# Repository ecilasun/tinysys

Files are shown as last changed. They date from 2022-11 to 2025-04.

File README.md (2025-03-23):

# tinysys

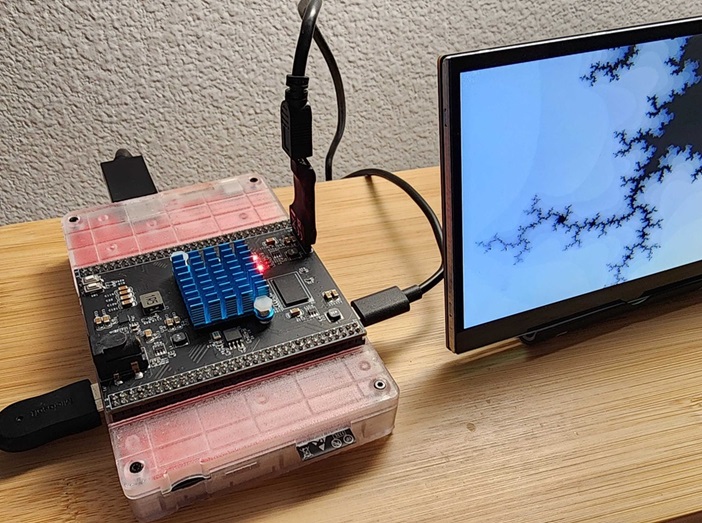
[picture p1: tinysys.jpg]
tinysys


# What is it?

Tinysys started out as a hobby project. It now has two RISC-V cores, and several other facilities listed below, and can happily run most software with minimal tweaks.

Of course, before you ask, it does run DOOM, and with sound and keyboard input! (Lately, it has been running Quake as well.)

# System specifications

- 2x RISC-V based CPUs (architecture: rv32im_zicsr_zifencei_zfinx)
- First core runs the OS kernel and user processes
- Second core is reserved for user processes
- 175MHz bus and CPU clock, semi-pipelined execution
- Vectored or direct interrupt support
- Supports instruction fence and data cache flush/invalidate operations
- Single precision FPU per CPU (no float control CRSs)
- Float and integer GPRs share the same register space (zfinx extension)
- 32 GRPs x 32 bits
- 4096 CSRs x 32 bits (some registers reserved for CPU and some are immutable)
- All CPUs have access to each-other's CSR register files via memory mapped addresses
- Integer multiply / divide units per CPU
- Software, hardware and timer interrupts per CSR per core
- 16Kbytes of direct mapped instruction cache (256 lines x 64 bytes)
- 32Kbytes of direct mapped data cache (512 lines x 64 bytes)
- 128 bit AXI4 bus with 32 bit address line
- Memory arbiter for on-board device system memory access (round-robin)
- Memory mapped external hardware (audio / video etc)
- HDMI 1.4b compatible video and audio output via external chip (12 bits per pixel, 16bps stereo 44/22/11KHz for audio, RGB or paletted modes)
- SDCard for file I/O
- 4 debug LEDs (also shared by OS as indicators)
- Custom preemptive multitasking OS, with file I/O and basic memory allocator via syscalls
- Optionally, a rom.bin image can be loaded from SDCard to replace the OS in ROM
- ESP32S3 on board for I/O handling (UART serial connected directly for CLI and other future connectivity, running at 460800 baud)
- Future revisions will use USB-OTG on the ESP32S3 module to allow for mass storage access to the device
- 16Kbytes mailbox memory for task scheduler + general purpose use (uncached)
- 16Kbytes of scratchpad memory for inter-processor communications or temporary data storage (uncached)
- Horizontal blanking interrupts to synchronize CPU with VPU for video effects or interrupt driven vsync page flip

# Overview of the processing units

## CPU
Based on 32 bit RISC-V ISA. Implements base integer instruction set, required cache operations (I$ and D$) and a large CSR file.
The core currently has an average instruction retirement rate of ~6 CPI (clocks per instruction) and runs at 175MHz, which
is also the speed of the AXI4 bus, where all peripherals and memory reside.

### Fetch/Decode/IRQ
This unit reads an instruction at PC, decodes it and outputs it (together with its PC) to instruction output FIFO (IFIFO). If it's an interrupt entry/exit or some other special instruction (for instance I$ flush) then it is handled entirely within the fetch unit. This unit is also responsible for inserting pre/post interrupt code from an internal ROM at interrupt or exception time. Conditional branches will place fetch unit into an idle state, where it will wait for the execute unit to resolve the target branch address. This means there's no branch prediction on the CPU just yet.

### Execute/Load/Store
This unit will read an instruction from the IFIFO if available, load registers with values, execute (ALU/BLU/CSR/SYS) and decide on new branch target if there's a branch involved. After deciding on the branch address, fetch unit is notified so it can resume instruction fetches. Where possible, load or store operations will attempt to overlap with fetch and execution.

## VPU
Video processing unit. Handles scan-out of various video sizes (320x240 and 640x480) and bit depths (8bpp index color or 16bpp RGB color). It contains a scanline cache which is populated via burst reads from system memory, from which either a scan-doubled or single line is output to the display, based on video mode height. The device allows for mid-frame change of resolution via hblank interrupts.

## APU
Audio processing unit. Handles RAW audio outputs, and also manages 44/22/11KHz stereo playback and double-buffer handling of RAW audio.

# Overview of the bus

## AXI4 bus
The AXI4 bus, running at 175MHz, connects all of the processing units to memory or devices. In the case of memory, access is cached per perhipheral as needed. Memory mapped device access is always uncached.

# Contributors

```
Martin Hedlund

  tbm_vsnprintf() and tbm_printf() functions

Wade Brainerd

  fcvtswu4sat instruction
```

# Custom instructions

## Convert from float to 4 bit integer, saturated (FCVTSWU5SAT)

This instuction has been contributed by Wade Brainerd. It's very useful in converting floating point values to device specific 4 bit color values.

The following python script helps encode a hex representation of this instruction, for convenience:

```
op = 0b1010011		# OP-FP (floating point operation)
rd = 0b01010		# destination register - a0 in this sample (a0 == x10)
rs1 = 0b01011		# source register - a1 in this sample (a1 == x11)
funct7 = 0b1100001	# funct5 F7_FCVTSWU5SAT - this is our new sub-instruction
inst = op | (rd << 7) | (rs1 << 15) | (funct7 << 25)

print(f"{inst:x}")
```

You can then use it in code as follows:

```
inline uint32_t ftoui4sat(float value)
{
  uint32_t retval;
  asm (
    "mv a1, %1;"
    ".insn 0xc2058553;" // fcvtswu4sat a0, a1 // note A0==cpu.x10, A1==cpu.x11
    "mv %0, a0; "
    : "=r" (retval)
    : "r" (value)
    : "a0", "a1"
  );
  return retval;
}
```

P.S. For the future we might be able to do this natively on a RISC-V or propose an extension for arbitrary saturation for custom formats.

# Software

Please see [README.md](./software/README.md) for details on software samples, ROM and prerequisites for building ELF files.

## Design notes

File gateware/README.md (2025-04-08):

# Latest Gateware Build is: 00203
# Latest OS ROM version is: 00152
# Latest ESP32 ROM is: r1.1H
# Latest Board version is: 2H

# Gateware binary
The gateware binary contains latest version of the device.
There is no need for a ROM file.<br>
If you have an older one, you can simply delete it, or use a `rom.bin` file with this version or higher.

# Current device architecture
This is the current architecture to use with gcc13 and higher: `rv32im_zicsr_zifencei_zfinx`

# ROM history
r1.01: Initial release version<br>
r1.03: Improvements for dual core boot stability, fixed audio hardware playback rate issue<br>
r1.06: Minor improvements to inner ROM loop and some other bug fixes<br>
r1.07: DMA hardware change in preparation for misaligned DMA support<br>
r1.08: Stability fixes<br>
r1.09: Added misaligned DMA support and removed ESP32/FPGA GPIO bridge device (to be re-done later), also added hblank interrupt mechanism and remote reboot ability (~ character over UART)<br>
r1.0A: Added 64Kbytes of scratchpad RAM, shared across all cores, WNS relaxed to leave room for any future bug fixes<br>
r1.0B: Minor device cleanup, reduced scratchpad to 16Kbytes, bumped mailbox to 16Kbytes<br>
r1.0C: Added a third CPU, CLI improvement to ROM and other minor fixes<br>
r1.1D: Improvements to reboot / task system and more ROM code cleanup, also updated file upload routines<br>
r1.1E: Updated UART to run at 460800<br>
r1.1F: Completely switched to ESP32S3 and new board(2G), added reset lines to UART, some helper tool and CLI improvements<br>
r1.1H: Removed DMA hardware due to complications, added experimental HDMI output for video/audio<br>
r1.3H: Some timing fixes and ROM code cleanup<br>
r1.4H: Slightly better timing, some hblank SDK and hardware work done (still not stable enough due to IRQ handling mechanism)<br>
r1.5H: Reduced I$ turnaround by one clock on cache hit<br>
r1.8F: Removed hblank device, updated ROM with fixes to task logic<br>
r1.9A: ROM updates with OS side input handling, software updates to match<br>
r1.9B: Minor changes to ROM and SDK routines, updates samples<br>
r2.0A: Added vectored interrupt support and bumped clock to 175MHz<br>
00201: Changed gateware versioning scheme, changed reset logic to full FPGA reset (clock and all clocked devices)<br>
00202: Task stack sizes bumped to 16K from 1K, watermark register now does not survive hard reset (only soft reset)<br>
00203: Bumped scratchpad to 64K, reset is more robust, updated ROM image with some memory fixes<br>
00151: OS updates for task errors<br>
00203: OS changes to same device version<br>
00152: OS changes (mainly for ELF loaded memory stomp)<br>
00203: Fixed float->uint conversion bug, keeping hardware version same<br>

# Device gateware

This folder contains the gateware that will reprogram the FPGA board on tinysys to a functioning RISC-V CPU with several other peripherals.

The intended device is the QMTECH A7200T core board, which is a blank FPGA board with nothing but an XCA7200T AMD/Xilinx part and a 256Mbytes DDR3 memory. The firmare also needs at least a revision 2E tinysys board to be attached to it to provide USB serial / HID / audio and video connections as well as the sdcard port.

Programmin the gateware onto the device requires a JTAG adapter (such as the HS2 REVA from Digilent or a Xilinx compatible 6-pin adapter), a PC, and Vivado 2024.1 installed.

NOTE: Make sure to never attempt this unless absolutely necessary and a hardware bug needs addressing / fixing or a new feature is added to the device!

# Programming

First we need to attach the JTAG adapter to the PC, and make sure the Vivado drivers are installed for it.

For this step, attach a USB cable to the HS2(revA or later), attach one end to your PC, then attach the adapter end to the 6 pin connector on the already powered-up FPGA board, as seen below:

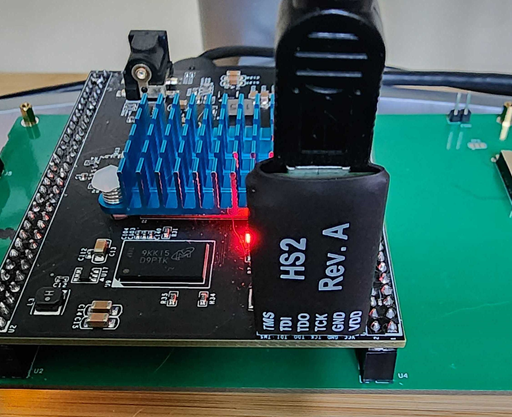
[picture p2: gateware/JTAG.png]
JTAG Connector


When properly connected, the text on the HS2 should be facing away from the board (easiest way to make sure it's correct is to find the GND marker on the 6 pin connector on the FPGA board, and line up the GND marker on the HS2 to that)

Start Vivado 2024.1 (or newer version) and on the first page, select Open Hardware Manager.
You should then see a note that says 'No hardware target is open.' Click the `Open Target` button next to it and select the `Auto Connect` option.

This should bring up a view which shows a 'xc7a200t' device listed. Right click on it and select `Add Configuration Memory Device`
In the search box, type `is25lp128f-spi-x1_x2_x4` and accept the changes.

Now this memory device should be listed unde the xc7a200t device, most likely below a XADC device.

Right click on the is25 and select `Program Memory Configuration Device`, then browse to and select the `tophat.bin` file in the gateware folder for the Configuration File.

Click OK and wait until the device is programmed (which will take a minute or so)

Once the progamming is complete, the device will not function until it's reset. Press the program/reset button (the small white button closer to the power connector barrel) and the device will reboot itself with the new gateware.

NOTE: the ROM image used by an updated gateware may differ from the one on the sdcard, make sure to either delete the one on sdcard or update it to a version newer or same as the gateware one, to ensure correct operation.

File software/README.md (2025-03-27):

This folder contains the riscvtool helper utility, the ROM image, sample code and the SDK for tinysys.
> Please note that precompiled binaries for riscvtool have been provided for Windows and Linux, however if the supplied binaries do not run for you or if you wish to build a MacOS version, please rebuild them from source as explained below.

# Prerequisites

If you wish to actually run things on a real piece of hardware:
- If you did not acquire / build one, please find the KiCad files for the board and go through the paces to build one
- Next step is to acquire (or use an existing) QMTECH A7200T core board (I'll build my own single board computer later, promise!)

If you wish to work on software:
- To be able to compile your own executables, or ROM images, you'll need a prebuilt gcc risc-v toolchain from the following link.
<br>(NOTE: The default compiler setup for samples and ROM images uses gcc, so please make sure to get that package)
<br>https://embecosm.com/downloads/tool-chain-downloads/#risc-v-embedded-stable-release-compilers
- In case you need it, you can find 'make' binaries here:
<br>https://gnuwin32.sourceforge.net/packages/make.htm
<br>(Make sure to also install libintl3 from same source and make sure it's on the path as well as the make.exe from the bin package)
- If you wish to build your own ROM images, you'll also need a working python3 install to make sure the waf build system functions as intended.
- To be able to compile riscvtool, you'll also need a working cpp compiler targeting the platform you're going to build on (windows/linux/macos etc)
- I advise using Visual Studio Code, but it's optional (all step below try to show both VSC and command line usage)
- To compile the ROM image and program the ESP32-C6 device (our communication module) for the first time, you'll need to install ESP-IDF addon for your Visual Studio Code
<br>See https://github.com/espressif/vscode-esp-idf-extension/releases/ for latest release

Or if you wish to simply browse / copy code or hardware details, feel free to do so, and don't forget to credit me and other people for their respective work!

# Build riscvtool (optional, required to build a new OS ROM)

If you wish to build new ROM images to experiment with, you'll need riscvtool which will generate the ROM binary format required by tinysys. You'll need a working python3 install for the following steps to work.

To build in Visual Studio Code:
- Open the 'software' directory in Visual Studio Code so that the root path is now /tinysys/software
- Use the ctrl+shift+b shortcut in Visual Studio Code and select 'configure'
- You can now ctrl+shift+b again select 'build', which will compile and generate the riscvtool for your platform

Alternatively, you can use the following command line sequences:
```
# To configure (required only once):
python waf --out='build/release' configure

# To build after code changes:
python waf build -v

# To 'clean' the output binaries
python waf clean
```
PS: The build process for riscvtool is the same on Linux and Windows.

# Building ELF executables

Please see [README.md](./samples/README.md) file in the samples directory

# Building ROM images

NOTE: Ordinarily you don't need to (and should not) build ROM images, there is one built into the gateware provided in the /gateware directory.

This is similar to building the samples, simply switch to 'ROMs/boot' directory and type:

```
make
```

This will give you one .mem file, and .elf file and a .bin file. The .elf file is not useful as a ROM image in this case, so you can ignore it.

The .bin image goes onto the sdcard, inside the '/boot' directory at the root of your FAT32 formatted sdcard. This image will be loaded by the resident ROM image and the device will chain to the code you've placed in this file, which is essentially how an OS update works for tinysys.

The .mem image is the actual physical ROM version of the same binary. If you don't plan to use an sdcard, the contents of the .mem file should be pasted over the 'Memory File/romimage.mem' file you can find in the project view. After replacing it, don't forget to 'Reset Runs' / 'Generate Bitstream' to generate your new gateware. (I recommend doing development using the .bin image and only replace the .mem once you're sure it's working to avoid lengthy development times, gateware usually takes about 20 minutes each run on a modetately fast desktop PC)

# Programming the ESP32 communications firmware

Tinysys uses an ESP32-C6 to communucate with the outside world. For this to function properly, the ROM image for the ESP chip has to be built. You need first plug in the previously-unprogrammed tinysys device, then open 'software/ESP32S3/defaultrom' in Visual Studio Code, and Hit the ESP-IDF 'Build, Flash and Monitor' button (looks like a little flame) to build and deploy it to the device.

# Default SDCard layout

Tinysys OS expects to find certain files in certain paths to function as expected. For instance, the 'rom.bin' file is expected to be in the '/boot' directory at the root of SDCard. Tinysys OS supports commands that can be executed from any directory (sort of a fixed $PATH if you will), and this is always expected to be 'sys/bin' Anything in that directory can be run from anywhere. Therefore it's a good place to put OS utilities or any used code that you might want to run from any path.

Therefore the default SDCard layout is:

```
sd:/sys/bin/... <- utility binaries, accessible from anywhere
sd:/sys/bin/rom.bin <- ROM overlay is always located here
```

# Creating your own project

To make your own project, the recommended way is to copy the 'hellodebugger' sample directory to a new one and make your changes as needed. In that directory you will find a Makefile, and upload shell script/batch file to help get you started.

Please refer to the [README.md](./samples/hellodebugger/README.md) file in `hellodebugger` folder for more assistance.

# Uploading your files to tinysys

There is an executable on the default disk image of tinysys, called 'recv.elf', under the sys\bin directory. The riscvtool binary can start this application remotely and start sending a binary file to it.

The syntax for sending a file is:
```
On windows:
riscvtool -sendfile myfile.elf
On Linux and MacOS:
./riscvtool -sendfile myfile.elf
```

The recv.elf executable will show an upload progress, and make sure the file arrives safely before writing it to the sdcard, as well as report any errors that might occur during the transfer.

# Other notes

NOTE: All software has been tested with and geared to use a gcc-riscv 32bit environment under Windows and Linux, but as always one might fall behind the other at times.

# Acknowledgements

I'd like to thank Wade Brainerd for help in getting this device tested thoroughly in a live environment, and for the awesome saturated float to integer conversion instruction.

Also thanks goes to Ben Stragnell for great advice and pointers in how audio hardware should work.

Further thanks goes to everyone who's build something on this machine at least once to put it through its paces.

Happy hacking!

Copyright 2025 Engin Cilasun

Please see respective license.txt files for individual license terms

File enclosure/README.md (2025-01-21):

# Enclosure

This directory contains SOLIDWORKS files for the enclosure, generated around board revision 2H

Enclosure:
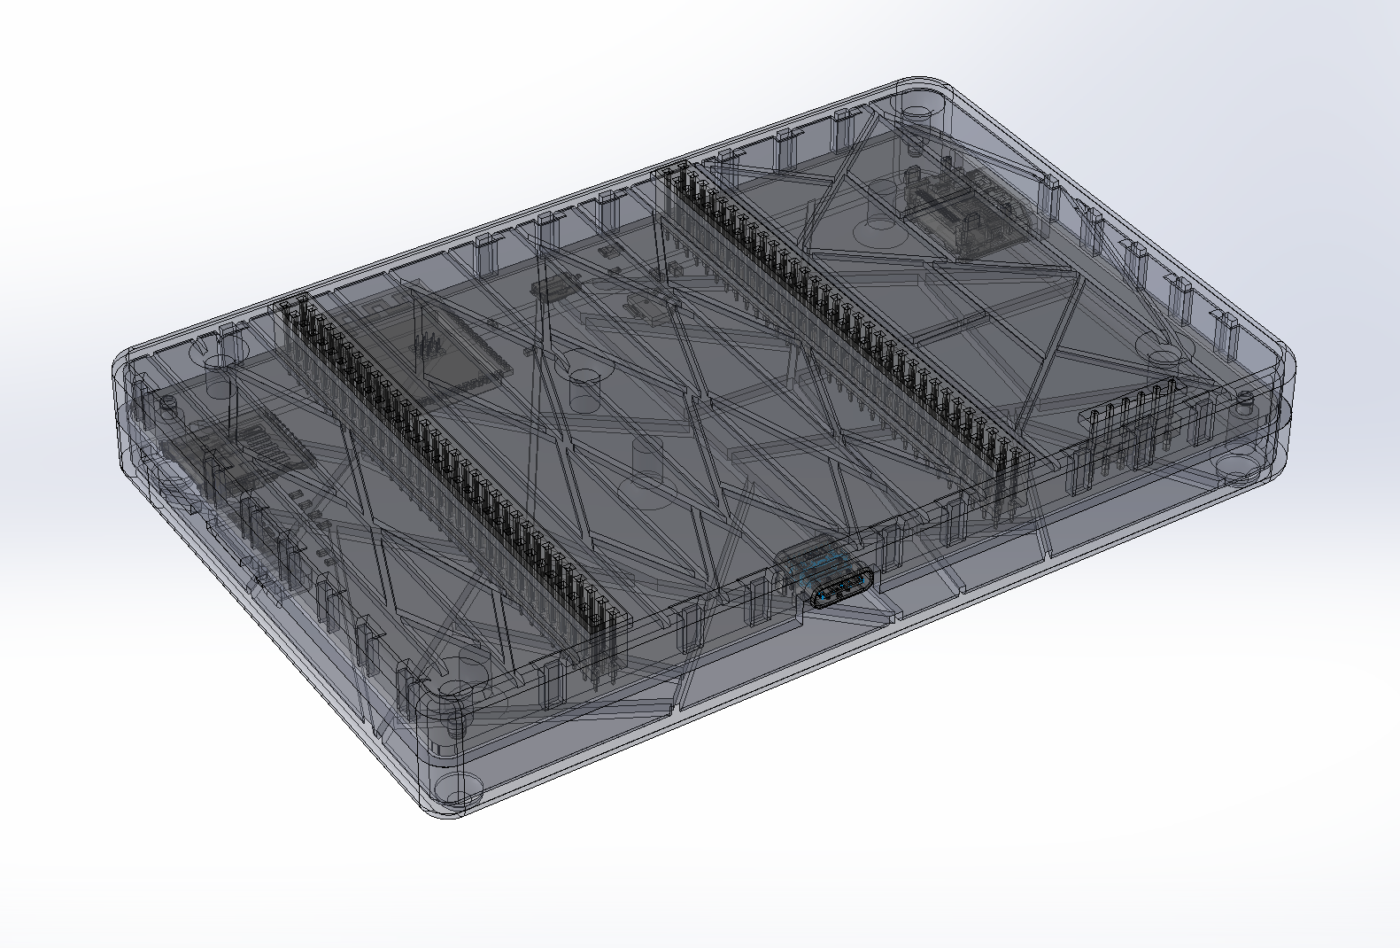
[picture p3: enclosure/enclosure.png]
Enclosure


Bottom:
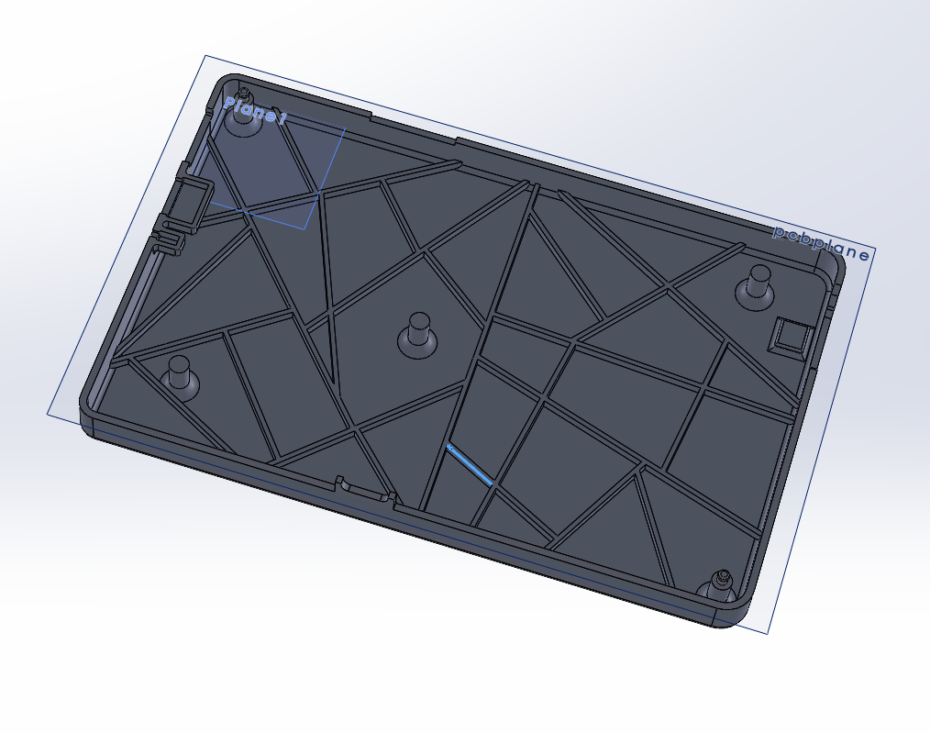
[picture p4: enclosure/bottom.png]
Enclosure Bottom


Top:
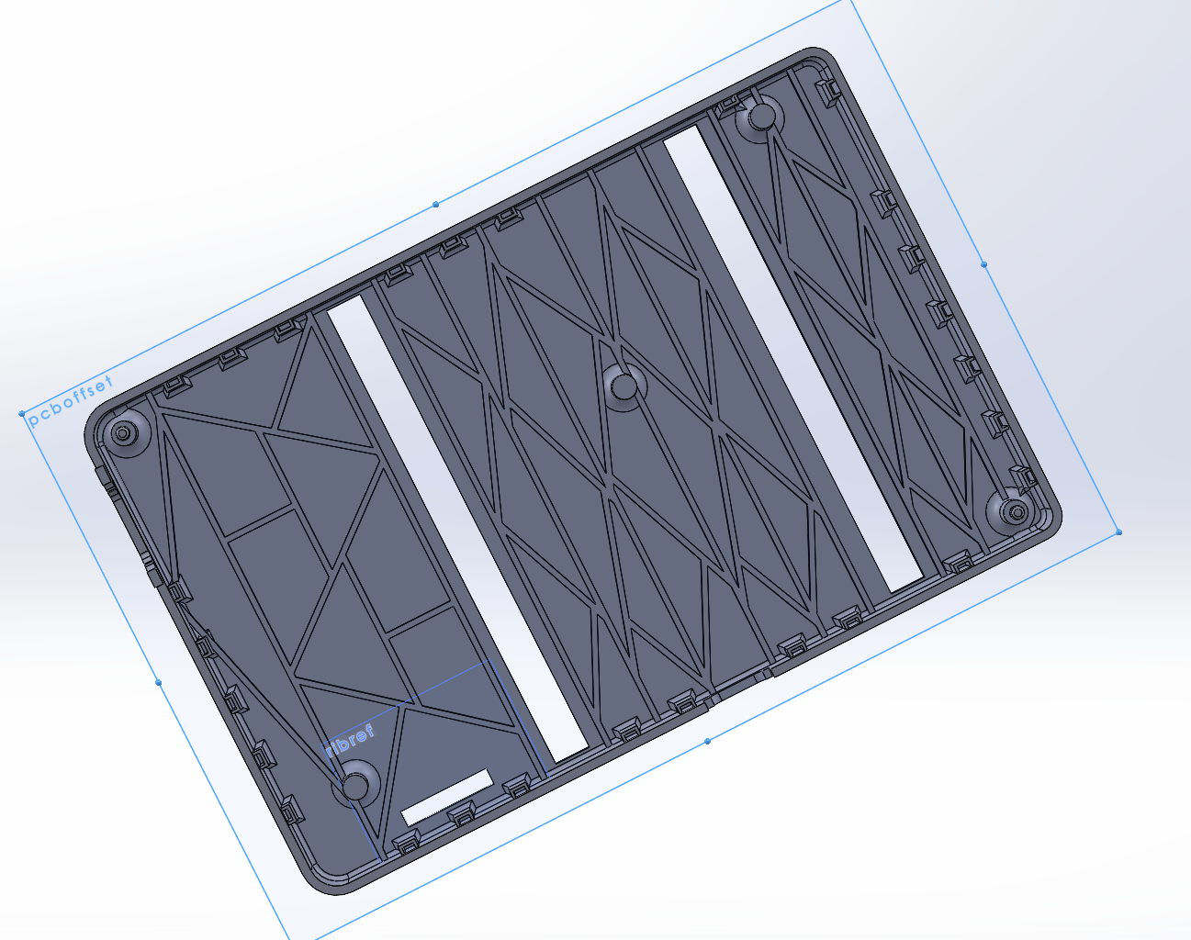
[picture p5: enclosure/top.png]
Enclosure Top


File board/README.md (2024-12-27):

# expansionboardA

This repository contains KiCAD 7 project files for an expansion module built for QMTECH A7 200T core board.
Required libraries (models and symbols) are included with the project.

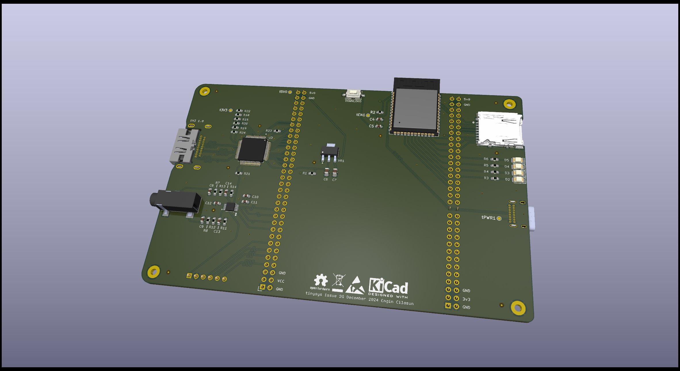
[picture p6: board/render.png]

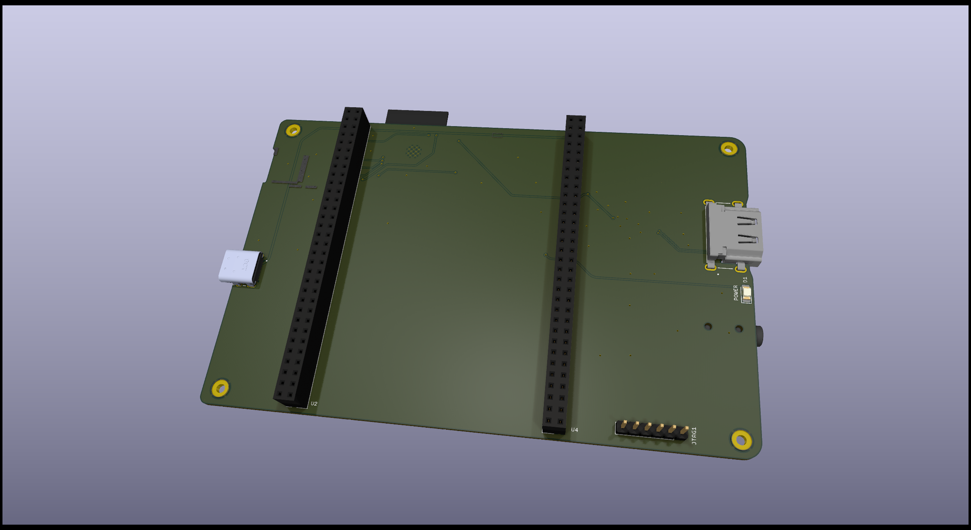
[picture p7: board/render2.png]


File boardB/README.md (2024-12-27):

# expansionboardB

This repository contains KiCAD 7 project files for an expansion module built for QMTECH A7 200T core board.
Required libraries (models and symbols) are included with the project.

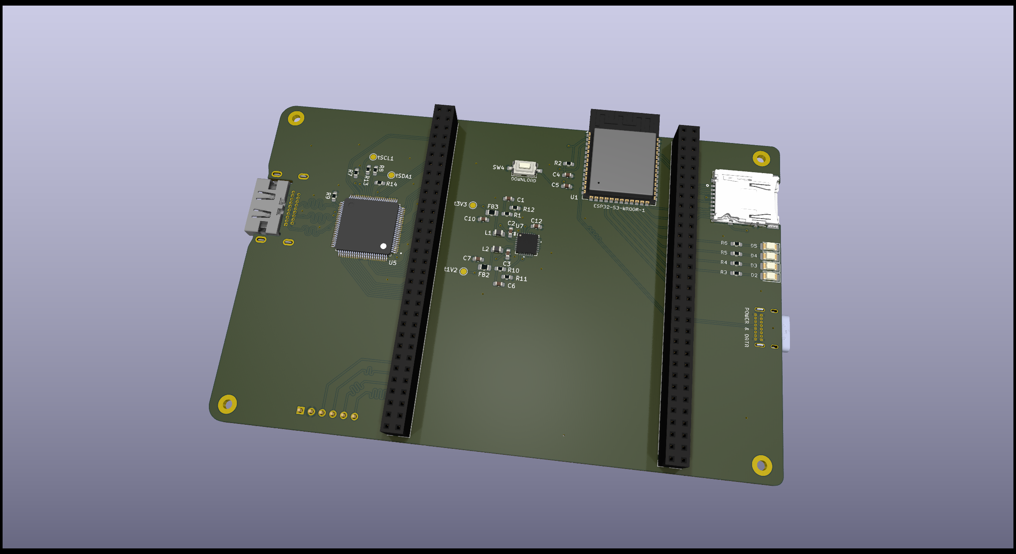
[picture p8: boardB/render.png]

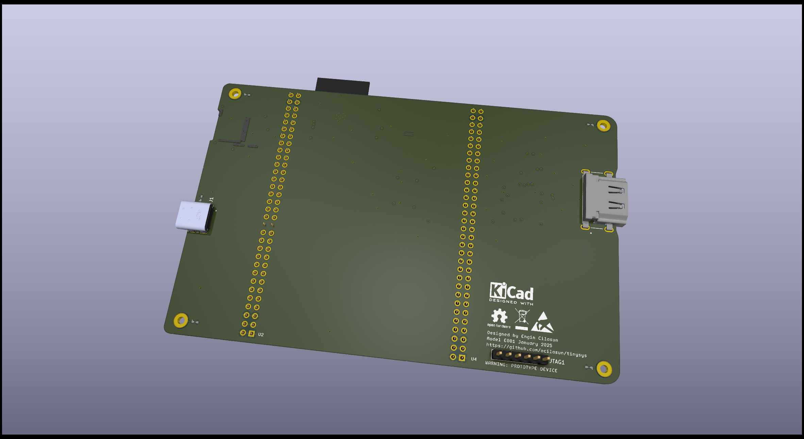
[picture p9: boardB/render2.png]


This board revision aims to unify audio and video into one device, and add a proper voltage regulation circuit. This revision is a 4 layer board instead of the previous 2 layer board.

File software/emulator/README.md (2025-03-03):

# What is this?

This is an emulator for the tinysys project

# Prerequisites
To build, please make sure you have at least version 2.3 of the following libraries available:
- libsdl2-dev
- libsdl2-ttf-dev

# Usage
To build the project, make sure you have C++ VC compiler tools installed, use the following sequence:
```
python3 waf configure -obuild/release
python3 waf build
```

Alternatively, you can use Visual Studio to build the emulator, using the emulator.sln solution file in the emulator/ folder

This will copy the emulator executable to the bin directory of project root folder, which you can then run using:
```
emulator.bat
or
./emulator.sh
```
depending on your OS.

The emulator will then scan the *sdcard* directory for executable files and generate a fake SDCard layout in memory which the emulator can access as if it's a real device.

To test your app, make sure the emulator is not running, drop your binary into the sdcard folder, and then start the emulator.

Following that, you can then run it by typing the name of your executable, excluding the .elf extension.

P.S. The emulator has been tested on latest macOS and Windows 11, Linux builds might require some manual work.

# Details

Here's a list of features implemented so far

- Dual CPU cores work with FPU (custom float->sat instruction included)
- Interrupts work
- UART is tied to console (I/O)
- Video output works
- There's a CPU stats overlay: update wscript to include the CPU_STATS define and rebuild if you wish to use it
- CSRs and their special purpose registers work
- MAIL device works
- LED device work with graphical representation present
- APU works and plays sound via SDL (including all playback frequencies supported by the real hardware)
- SPI sdcard emulator fully works
- GDB stub is working to a certain point, needs better breakpoint handling and single step support

And here's the list of what's missing

- ESP32-S3 module emulation is missing and won't be supported (don't want to deal with Xtensa emulation at this point)

Please note that this is not a clock precise emulation and instructions will almost always retire in 1 CPU clock. Also all devices clock at the same speed so there's going to be some mismatch there as well. Since the aim of this emulator is to provide a testbed for ROM or user software in the absence of real hardware, it should be close enough to get development rolling.

Wish list

- TODO

### Back to [SDK Documentation](../SDK/README.md)

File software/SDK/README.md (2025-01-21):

# SDK Documentation

## Base System
Base system routines provide useful facilities such as reading the clock, or setting up critical sections.

Please see [BASE](base.md) for documentation about base system utilities.

## Audio Processing Unit
The audio processing unit is responsible for generating stereo signals at various output frequencies.

Please see [APU](apu.md) for documentation about audio.

## Multitasking
The task library helps start and stop tasks that can run on any hardware thread in the system.

Please see [TASK](task.md) for documentation about multitasking and the CPU cores.

## Video Processing Unit
The video processing unit controls video scan out from selected system memory location as well as controlling color depth and video dimensions.

Please see [VPU](vpu.md) for documentation about video output control.

## Debug LEDs
The debug LEDs provide an easy means to debug code when there are no alternatives, or to show status.

Please see [LED](led.md) for documentation about debug LEDs.

## Emulator
The emulator tries to provide as close an experience to the real hardware as possible, including a virtual SDCard interface to make development easy.

Please see [EMULATOR](emulator.md) for documentation about debug LEDs.

## Low level hardware overview
The hardware of tinysys consists of an FPGA board that carries some custom devices and two RISC-V cores. The FPGA board lives on a custom board that contains some external peripheral chips that interface the board to the outside world, such as video, audio and USB connectivity.

Please see [HARDWARE](hardware.md) for brief information about the internal devices.

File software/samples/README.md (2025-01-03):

This folder contains the samples for tinysys

# Building samples

To build all of the samples, use the following command in this directory:

```
make
```

This will produce .elf binaries in each of the sample folders, which you can then copy onto an sdcard and run on the device.

If you wish to build just one, change to the desired folder and use the same make command.

# Running samples on the emulator

This initially requires you to build the emulator binaries.

First, check out the [README.md](..\emulator\README.md) for build instructions.

Once the emulator is built, next step is to drop your binary into the [sdcard](..\emulator\sdcard\README.md) folder and then start the [emulator.bat](..\emulator\emulator.bat) file.

The emulator will do its best to match the hardware, except the ESP32 device which is not currently emulated.

# Running samples on the actual device

Once the dev environment is set up and riscvtool has been compiled, first switch to the desired directory on the device using:

```
cd somedirectory
```

then use the following command to send files across to the actual device:

```
On windows:
riscvtool -sendfile myprogram.elf

On Linux and MacOS:
./riscvtool -sendfile myprogram.elf

Alternatively, you might want to provide a COM port name:
riscvtool -sendfile \\.\COM6 myprogram.elf
```

followed by the name of your binary + Enter:

```
myprogram
```

to execute the binary.

The file transfer code will split the file into chunks, lz4 pack them, and send them across serial connection to be reconstructed into a file on the device.

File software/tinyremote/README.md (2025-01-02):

# TinyRemote

Tinyremote can be used to connect to a tinysys board on a remote machine and control it while being able to see the video output.

Currently it only supports Linux and Windows, but future support for MacOS is also in the works.

Build prerequisites on Linux:

```
sudo apt-get install libx11-dev libv4l-dev libv4l-dev libsdl2-dev libsdl2-ttf-dev
```

Windows includes the required SDL headers and binaries in the 3rdparty folder.

For MacOS, SDL2 and SLD2_ttf have to be installed via homebrew and reside in the following paths at the time of writing:

```
/opt/homebrew/Cellar/sdl2/2.30.5/include/SDL2
/opt/homebrew/Cellar/sdl2/2.30.5/lib/

/opt/homebrew/Cellar/sdl2_ttf/2.22.0/include/SDL2
/opt/homebrew/Cellar/sdl2_ttf/2.22.0/lib/
```

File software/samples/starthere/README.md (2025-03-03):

# Welcome to your project!

First step is to create a copy of this folder under the samples directory, and rename it to match your project title.

After this, you'll want to rename the output file names from `starthere` to your project name in the Makefile.

Once that is out of the way, we can begin!

# What is this tinysys?

Tinysys is a simple computer with two 32 bit RISC-V cores. It has no branch prediction, no pipelining and will run at approximately 27MIPS, and has a coremark score of 0.54 to 0.6 depending on the configuration

However slow it might seem, it makes up for what it lacks with a few hardware devices implemented in the FPGA fabric. To see the speed at which memory can be moved around, run the `memtest` sample for CPU side memory clear speed.

There's a mini OS (~52Kbytes) provided in ROM which contains the necessary routines to help with file access, memory allocation and other facilities.

The SDK directory contains quite a few modules and combined with the samples you should have a good idea of what the device can achieve.

# Compiling and running your project

Tinysys is a very simple machine so it requires little more than a few files to do something useful. Observe the layout of the provided Makefile and make necessary changes as you see fit. Only thing to watch out for are the machine architecture and cache size/alignment flags. Rest is up to you!

To run the resulting .elf file, you have two choices.

You can use the riscvtool to send the compiled binary to the machine using base64 encoded format. First, got the directory where your binary is, and use the following command:

```
On windows:
riscvtool -sendfile myfile.elf
On Linux and MacOS:
./riscvtool -sendfile myfile.elf
```

This will start a progress bar and copy the file to the target device, however since base64 encoding expands a file, it will not complete this transfer quickly. The file is written to the SDCard at the current directory.

Alternatively, you'll need to copy your binary onto a FAT32 formatted SDCard, insert the card into the machine.

After either method, type the name of your binary (without the .elf extension) from a connected terminal or keyboard, and the binary will start executing.

If you wish to stop execution, use CTRL+C to break out of the application.

If your system appears to be unresponsive, use the tilde key (~) to break the execution from a connected terminal (this will not work with a keyboard, in that case assuming you're close to the device, please use the reset button on the board instead)

# Debugging this sample

'starthere' sample is deliberately unoptimized to act as our debugging sample. To start debugging, first start the executable from the samples directory on the emulator. Then, from the tinysys\software directory, run the following to load the debug symbols and start a GDB session:

```
riscv32-unknown-elf-gdb.exe -x gdbcmd samples/starthere/starthere.elf
```

This will start GDB but assume the remote executable has stopped when it's connected. At this point you can add a new breakpoint using the 'b' command and then use 'c' to continue exectuion. This will update the breakpoints on the device and stop execution on the closest line possible (depending on optimizations and line number information available to GDB)

Alternatively, start the sample on the device and open the software folder in VSCode, then hit 'Run' which by default loads the 'starthere' sample debug data. You can now debug on the device as usual. Please modify the launch.json file and change the "program" entry to your own executable as needed.

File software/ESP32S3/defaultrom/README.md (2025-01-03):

# Firmware for the on-board ESP32-S3-WROOM-1 module

This firmware allows the ESP32 to act as a communications processor for tinysys.

The default firmware behavior is to pass through serial data coming from USB to the UART pins connected to the FPGA and also provide the same function in the opposite direction.

In additon, sending the character '~' with no following character within a certain amount of time will pull a reset line to reboot the CPUs on tinysys, therefore the ESP32 can be used as a recovery device for code that gets stuck when developing remotely (when no button access is possible)

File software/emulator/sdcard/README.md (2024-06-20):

Drop the contents of this folder to the root of a FAT32 formatted sdcard, place it into the tinysys board's sdcard slot and reboot.
This will get tinysys to reboot from the .rom image on this folder and you'll have all the samples precompiled so you can test them quickly.
NOTE: The elf files in the sys/bin directory can be run from any folder, so you might want to place any new binaries that you wish to use as 'commands' into that folder.

In addition, this folder will be used by the emulator so you can test the samples without having to flash the board.

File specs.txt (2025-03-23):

CPU:
32 bit CPU running at 175MHz, approximately 5 clocks per instruction
Vectored or direct interrupt support
Based on RISC-V architecture
Implements the rv32im_zicsr_zifencei_zfinx feature set (32bit base instruction set, intereger div/mul, combined float+integer register file, 4096 control/status registers, I$/D$ fence and flush instructions, software/hardware/timer interrupts)
16Kbytes instruction cache
32Kbytes data cache
64Kbytes of ROM for the OS
No branch prediction
No pipelining
No memory management unit (i.e. no virtual memory)

Memory:
256MBytes of DDR3 SDRAM
Cached access from CPU and direct access from other devices on the bus, in 128bit bursts

Devices:
Memory mapped access to the following devices:
- Device temperature monitor, accessible from user software
- Video and 16 bit stereo audio over HDMI port (640x480 or 320x240 modes with 8bpp indexed or 16bpp truecolor for a total of 4 modes)
- SDCard slot
- USB-C port for serial connection to a host PC / power
- USB-A port for peripheral connectivity
- 4 user / debug LEDs (currently used by OS for status indication, user software can also access these)

OS:
Custom OS in ROM with preemptive multitasking, copied to RAM at boot
Can instead chain to user binary from SDCard (rom.bin at root)
Runs ELF files generated by riscv gcc13 directly (riscv64-unknown-elf-gcc with 32 bit output)
Implements memory allocation (s_brk) and file IO syscalls
Handles serial I/O via MAX3420E
Handles host features via MAX3421E and implements host device drivers (keyboard/mouse/joystick)
Implements a simple CLI that can execute basic maintenance tasks / load ELF files from storage
Currently runs 2 OS threads + 1 user ELF

NOTES:
The custom board that houses this system contains two USB control chips, one audio DAC and the SDCard reader, one soft-reset button, as well as connectors for peripherals and power. There is also a 5v to 3v3 conversion circuit so that the power can be drawn from the USB-C port.
The board is designed to carry a QMTECH A7-200T FPGA core board (i.e. it has nothing more than a blank FPGA, one DDR3 SDRAM chip, and power circuitry). The entire system is implemented in SystemVerilog to run inside this chip.
Future revisions of the board will include this chip directly onboard so that'll cut the requirement for an daughterboard, but for this version that's one thing that limits number of devices that can be made

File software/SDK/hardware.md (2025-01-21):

# Hardware overview
Even though tinysys looks like a functioning computer, it is in fact implemented on a prototyping board and is written entirely in SystemVerilog language.

The SV description of each hardware unit is then converted to a list of connected gates, which forms the gateware.

The nature of FPGAs do not allow for gigahertz level clocks on the low end consumer / automative versions, but what they lack in speed they make up for in versatility.

This allows for some really specialized hardware that can access data via very wide busses, and true parallel device execution.

### The CPUs
RISC V is the CPU of choice for tinysys, though it could easily have been OpenRISC or a combination of other CPU designs to form a heterogenous system.

For easer of development, the choice was made to implement the open RISC V standard, as there are mature enough compilers and tools today that allow for portin complex applications including Linux to this architecture.

There are multiple CPUs on board (inside the FPGA) of tinysys. Technically, they're termed 'hardware threads' and the term HART is used for short.

Each HART contains its own dedicated data (D$) and code (I$) cache, which are 32 and 16 Kbytes in size respectively.

There is a floating point unit (without the classification and exception mechanisms implemented) on the device per HART, which handle single precision floating point math operations. The floating point registers share the same space as integer registers, which allows for a very simple task switching approach, where one does not need to spend clock cycles to store/restore FPU registers or their corresponding FPU control CSR.

### Memory
The memory controller of tinysys currently uses the Xilinx DDR controller IP, which is set up to work in 128 bit burst mode.

The cache controllers aim to return data and code fast and not access memory as much as possible, which helps execution speeds as expected.

The only downside is that, due to the nature of how this cache works, data is not delivered in a single clock cycle and might take from 3 to 4 cycles. This is still faster than hitting memory, populating the cache, and returning data form the now-correctly-populated cache.

### Memory layout

The memory address space has been divided into RAM and devices, at address 0x80000000.

All devices are placed at addresses 0x8... onwards, and system RAM starts at address 0x0... This is the opposite of what most embedded CPUs do, but for ease of software development tinysys has adopted this layout.

The device memory space is split into 64Kbyte regions. Not all devices have access to the full 64Kbyte memory space, except the scratchpad memory at address 0x80000000.

Here is a list of all devices, their starting addresses, and their purpose. Please note that this is for illustration purposes only; it is highly recommended to use the corresponding device functions from the SDK instead of these numbers so that the code is compatible with future OS/device changes.

> **Warning:** Accessing any memory regions outside the following, or those reserved by the OS will most likely hang the hardware and require a reset. Try to adhere to memory allocation functions and utilities provided in the SDK files to get valid addresses when possible to avoid this scenario.

```
	SYSTEM_RAM  0x00000000 - 0x0FFFFFFF OS RAM: 256Mbytes of system memory, further subdivided into dedicated regions by the OS
	DEVICE_SPAD 0x80000000 - 0x8000FFFF Scratchpad: 64Kbyte word addressible, uncached memory, accessible from all cores coherently
	DEVICE_LEDS 0x80010000 - 0x8001FFFF Debug LEDs: 4 LEDs that are on board the device, suitable for simple debugging purposes
	DEVICE_VPUC 0x80020000 - 0x8002FFFF VPU fifo: Command fifo for the video processing unit (VPU)
	DEVICE_SPIC 0x80030000 - 0x8003FFFF SPI fifo: Command fifo for the SPI device tied to the SDCard controller
	DEVICE_DEV0 0x80040000 - 0x8004FFFF Unused - reserved for future use / do not access
	DEVICE_USBA 0x80050000 - 0x8005FFFF USB fifo: Command fifo for the SPI device tied to the USB host chip
	DEVICE_APUC 0x80060000 - 0x8006FFFF APU fifo: Command fifo for the audio unit, used to control audio playback
	DEVICE_MAIL 0x80070000 - 0x8007FFFF Mailbox: A 4Kbyte word addressible uncached memory region used to store task state for the scheduler
	DEVICE_UART 0x80080000 - 0x8008FFFF UART: I/O port used to read from and write data to the UART device tied to the ESP32-C6 module
	DEVICE_CSR0 0x80090000 - 0x8009FFFF CSR0: The 4Kbyte memory mapped CSR file for hardware thread zero
	DEVICE_CSR1 0x800A0000 - 0x800AFFFF CSR1: The 4Kbyte memory mapped CSR file for hardware thread one
	DEVICE_DEV1 0x800B0000 - 0x800BFFFF Unused - reserved for future use / do not access
	DEVICE_DEV2 0x800C0000 - 0x800CFFFF Unused - reserved for future use / do not access
	DEVICE_DEV3 0x800D0000 - 0x800DFFFF Unused - reserved for future use / do not access
	DEVICE_DEV4 0x800E0000 - 0x800EFFFF Unused - reserved for future use / do not access
	DEVICE_DEV5 0x800F0000 - 0x800FFFFF Unused - reserved for future use / do not access
```

### Memory arbitration
There is a memory arbiter implemented in the FPGA fabric, which is the backbone of all I/O coming from the CPU or other devices.

This unit can deal memory access using round-robin arbitration where each device gets a fair share of the memory bus.

The CPUs, audio DMA and the VPU scanline buffer are the main clients of this bus. All of the internal hardware also live on the bus as uncached memory mapped devices, such as the command FIFOs for most devices.

When video scan-out is enabled, the CPUs will share memory access with the VPU, and the VPU will take up most of the read bandwidth while it's populating its scan-out cache. This means, for memory I/O intensive algorithms, one might benefit from turning off video scan-out slightly, for example when startup up a game that needs to generate some procedural data.

### Hardware interrupts
Most of the devices, such as the USB module or the SDCard module, will generate EI (external interrupts) when certain conditions occur, such as inserting or removing an SDCard, or when a horizontal scanline is encountered, depending on setup.

In addition to the peripheral interrupts, there is a timer interrupt that will periodically fire. This interrupt type is how the task system implements its scheduler. Each task is given a 'timeout' value after which they will break execution and switch to the next, or if so desired, preemt execution by calling `TaskYield()`. In all cases, the timer control registers are utilized to trigger the scheduler interrupt on each HART so they can manage their task pools simultaneously.

Last one is the software interrupt facility, which currently tracks illegal instruction execution.

All of these interrupts are in use by the OS for specific work, however there is nothing in the hardware design that enforces OS level control over these. Implementing a custom rom.bin and placing it into the /sys/bin/ folder at the SDCard root will allow for overriding everything, including the interrupt mechanisms, that tinysys offers.

### ESP32 communications helper
There is an ESP32 chip on board (which also uses a RISC V core) that is hard wired to act as the USB(or Bluetooth)-serial converter. The serial input received feeds into the serial input buffer by the OS via interrupts, which in turn feeds the keyboard entry buffer. This means one can send text commands over USB or Bluetooth of a cell phone to the device while the OS terminal is alive.

### Back to [SDK Documentation](README.md)

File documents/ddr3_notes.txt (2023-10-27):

MT41K128M16JT-125:K

See these links for MIG setup for the 125K part
https://blog.csdn.net/neufeifatonju/article/details/104915776
https://forum.digilent.com/topic/2709-which-memory-chip-on-the-arty/

Max clock period: 3000ps (667Mbps for -1 parts)
Recomm. input clock: 6000ps (166.6667MHz)
Voltage: 1.35V
Data width: 16
Data mask: enabled
RZQ/6 - RZQ/6
Internal vref: enabled
Internal term. impedance: 50 Ohms

non-industrial, commercial part
128M16-> configured as 128 Meg 16
JT->96 ball 8mmx14mm FBGA package
125->tCK=1.25ns,CL=11 (DDR3-1600)

• LOW: VIN ≤ VIL(AC)max; HIGH: VIN ≥ VIH(AC)min.
• Midlevel: Inputs are VREF = VDD/2.
• RON set to RZQ/7 (34Ω
• RTT,nom set to RZQ/6 (40Ω
• RTT(WR) set to RZQ/2 (120Ω
• QOFF is enabled in MR1.
• ODT is enabled in MR1 (RTT,nom) and MR2 (RTT(WR)).
• TDQS is disabled in MR1.
• External DQ/DQS/DM load resistor is 25Ω to VDDQ/2.
• Burst lengths are BL8 fixed.
• AL equals 0 (except in IDD7).
• IDD specifications are tested after the device is properly initialized.
• Input slew rate is specified by AC parametric test conditions.
• ASR is disabled.
• Read burst type uses nibble sequential (MR0[3] = 0).
• Loop patterns must be executed at least once before current measurements begin

PINS:
DDR_RESETN T2
DDR_CLKP J7
DDR_CLKN K7
DDR_CS L2
DDR_RAS J3
DDR_CAS K3
DDR_WE L3
DDR_D0 E3
DDR_D1 F7
DDR_D2 F2
DDR_D3 F8
DDR_D4 H3
DDR_D5 H8
DDR_D6 G2
DDR_D7 H7
DDR_D8 D7
DDR_D9 C3
DDR_D10 C8
DDR_D11 C2
DDR_D12 A7
DDR_D13 A2
DDR_D14 B8
DDR_D15 A3
DDR_DQS1P C7
DDR_DQS1N B7
DDR_DQS0P F3
DDR_DQS0N G3
DDR_DQM1 D3
DDR_DQM0 E7
DDR_A0 N3
DDR_A1 P7
DDR_A2 P3
DDR_A3 N2
DDR_A4 P8
DDR_A5 P2
DDR_A6 R8
DDR_A7 R2
DDR_A8 T8
DDR_A9 R3
DDR_A10 L7
DDR_A11 R7
DDR_A12 N7
DDR_A13 T3
DDR_BA0 M2
DDR_BA1 N8
DDR_BA2 M3
DDR_ODT K1
--
DDR_VREF M8
DDR_VREF H1

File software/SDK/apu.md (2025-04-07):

# Audio Processing Unit

The APU consists of a commmand FIFO an internal hardware to stream out audio at a chosen rate, and an external audio chip (Cirrus Logic, CS4344-CZZR, stereo D/A converter) that listens to sound data over an I2S bus.

The internal audio device can drive the DAC using stereo 16bit samples, clocked at 44Khz, 22Khz or 11KHz sample rates.

APU has an internal memory region which is split into two pages. One of these pages is called the 'write page' and can be written by the CPU using the `APUStartDMA()` function. The other page is the 'read page' and is dedicated to feeding the audio chip and can't be touched by the CPU while playback is in progress.

When the APU reaches the end of the current read page, it will toggle the two pages and flip a counter bit. This mechanism can be used to wait for audio playback to complete to queue more samples.

See the playing audio section below for details on how this system works.

# Command FIFO

The command fifo accepts the following command codes as 32bit words, followed by zero or more words containing data as required.

To write a command, the SDK functions simply write the command word and the parameters to the FIFO at memory address `0x80070000`

However, to be compatible with future hardware, it is advised that the writes go through the SDK functions listed below.

### Allocating CPU side audio buffers
`uint8_t *APUAllocateBuffer(const uint32_t _size)`

This function will allocate a 16 byte aligned region of `_size` bytes of memory that can be used for your mixer output.

To copy this data to the write page of the audio device, call the `APUStartDMA` function shown below.

### Set audio buffer size
`void APUSetBufferSize(uint32_t audioBufferSize)`

This command will set the source sample buffer size (and the output size) of audio data.

### Start audio data DMA
`void APUStartDMA(uint32_t audioBufferAddress16byteAligned)`

This command will start copying new bytes to the write page of the audio device, while the playback page is still outputting samples.

The `audioBufferAddress16byteAligned` parameter should point at 16 bit stereo audio data located at a 16 byte aligned address.

### Set audio output rate
`void APUSetSampleRate(enum EAPUSampleRate sampleRate)`

The `sampleRate` parameter can be one of the following 2 bit binary values (packed into lowest two bits of parameter word):
```
ASR_44_100_Hz: Set audio output rate to 44.1KHz
ASR_22_050_Hz: Set audio output rate to 22.05KHz
ASR_11_025_Hz: Set audio output rate to 11.025KHz
ASR_Halt: Stop audio output
```

### Tracking playback state
`uint32_t APUFrame()`

This function will return either 0 or 1, depending on which page is now available for writes by the CPU.

### Playing audio

To play audio, first we need to initialize the audio system by allocating some mixer memory and deciding on the audio playback rate.

```
#define BUFFER_SAMPLES 512
apubuffer = (short*)APUAllocateBuffer(BUFFER_SAMPLES*NUM_CHANNELS*sizeof(short));
APUSetBufferSize(BUFFER_SAMPLES);
APUSetSampleRate(ASR_22_050_Hz);
```

Next step is to read which page is our write page by calling the following sequence of instructions:
```
uint32_t prevframe = APUFrame();
```

Now we can sit in a loop and push new audio data every time `prevframe` value mismatches the new `APUFrame()` value:
```
do{
	// TODO: fill apubuffer with some stereo 16 bit audio data
	CFLUSH_D_L1(); // Make sure the CPU writes can be seen by the DMA device by flushing them to memory
	APUStartDMA((uint32_t)apubuffer); // Kick new data to the APU

	// Wait for the sample playback to finish.
	// This means the APU has reached the end of the read page and has set the other page as the new read page.
	uint32_t currframe;
	do
	{
		currframe = APUFrame();
	} while (currframe == prevframe);
	prevframe = currframe;

	// See task.md about this command
	TaskYield();
} while(1);
```

For a full sample that can play mod/xm files, please see the sample code in 'samples/mod' directory

### Back to [SDK Documentation](README.md)

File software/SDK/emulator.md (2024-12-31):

# Emulator

The emulator for tinysys is aimed to be fast instead of clock-accurate.

It implements functionality of all onboard peripherals except the Xtensa CPU of the ESP32-S3 module. This unit is wired to reset the CPUs and read/write from/to the terminal of the host PC over a UART connection. It isn't required for the emulator, as it pulls its own keyboard input from a fake UART device.

Please see [EMULATOR](../emulator/README.md) for more information about how the emulator can be used for development.

### Back to [SDK Documentation](README.md)

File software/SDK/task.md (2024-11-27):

# Multitasking

The OS on tinysys implements a hardware timer driven preemptive scheduler, and a few utility functions to aid in task generation.

This allows the OS to run several tasks, one of which is the user process, as well as allowing the user process to enqueue and run tasks of its own.

Tasks can yield execution to other tasks by calling the `TaskYield()` function. This function will only have an effect on the calling CPU and won't change the scheduling on other CPUs.

The task system can access the task context of other CPUs in the system from any other CPU, which allows for user tasks (always running on HART#0) to spawn tasks on either HART#0 or HART#1

### Accessing the OS task context
`struct STaskContext *TaskGetContext(uint32_t _hartid)`

This function returns the task context for a given CPU. Use the returned data pointer with care, directly modifying the returned memory contents is not recommended.

Use the returned context as the `_ctx` parameter for functions listed below.

### Shared uncached dmemory
`void *TaskGetSharedMemory()`

This function will return a shared memory space for HART to HART communications. The memory is uncached, so all writes from one HART are immediately visible to all other HARTs.

### Adding a new task
`int TaskAdd(struct STaskContext *_ctx, const char *_name, taskfunc _task, enum ETaskState _initialState, const uint32_t _runLength)`

This will enqueue a task to be executed the next time scheduler reaches the last task in the current task list. The `_initialState` parameter should ideally be set to `TS_RUNNING` or if need be, to `TS_PAUSED` and none of the other values available. Doing so might break the consistency of the scheduler.

The `_task` function has to have a signature that matches the following:
```
typedef void(*taskfunc)();
```

The function will return a handle to the task created, which can then be stopped by calling the `TaskExitTaskWithID()` function listed below.

### Yielding time to other tasks
`void TaskYield()`

This function switches to the next task in the queue for the calling CPU, as quickly as possible.

Call this function in a tight loop that might be blocking other tasks or the OS, to yield time back to the calling CPU's scheduler before the task's run length is up.

### Stopping a task
`void TaskExitTaskWithID(struct STaskContext *_ctx, uint32_t _taskid, uint32_t _signal)`

This function can be called with the same handle returned from the `TaskAdd()` function. Upon exiting, the return value of the task will be determined by the `_signal` value.

### Using the task system

For a full sample that uses the task system that prints a string and runs the debug LEDs simultaneously, see the sample code in 'samples/task' directory

### Back to [SDK Documentation](README.md)

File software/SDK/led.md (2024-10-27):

# Debug LEDs

Debug LEDs are useful to reflect status when there is no chance to modify onscreen bitmaps, use the UART or generate audio. They can be useful visual clues to aid in debugging your software.

### Debug LED status
`uint32_t LEDGetState()`

This function will get the current state of the debug LEDs. Only the lower 4 bits have meaningful values, and each of these low bits correspond to a single physical LED on the device.

`void LEDSetState(const uint32_t state)`

This function will control the state of the debug LEDs on the device. Setting one of the lowest 4 bits will turn the corresponding LED on.

Upon termination of a process, all LEDs will revert back to off state.

### Using the debug LEDs

For a full sample that blinks the debug LEDs, see the sample code in 'samples/led' directory

### Back to [SDK Documentation](README.md)

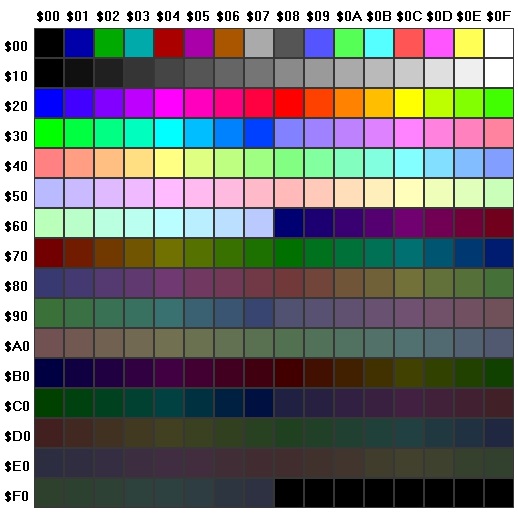
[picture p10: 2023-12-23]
vgapalette.jpg

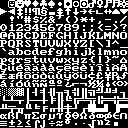
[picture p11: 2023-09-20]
assets/vga2_8x8.png

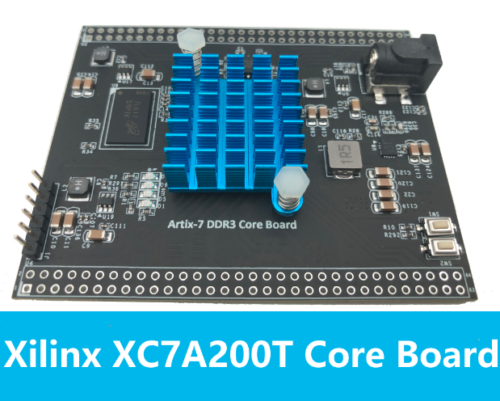
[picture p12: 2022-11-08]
documents/s-l500.png

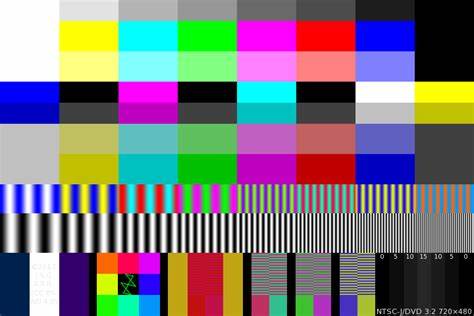
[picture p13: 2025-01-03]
software/emulator/sdcard/jpeg/ntsc.jpg

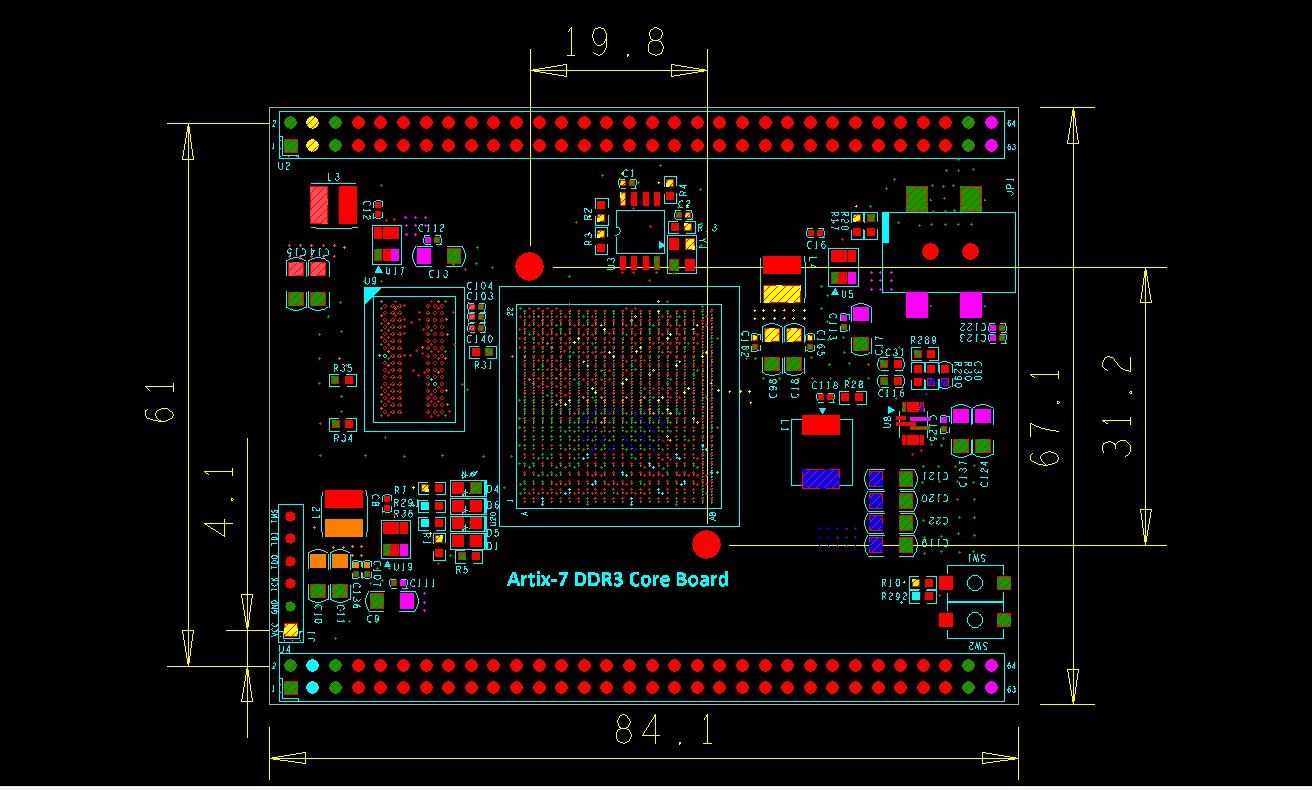
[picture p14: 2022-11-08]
documents/qmtech board.jpg

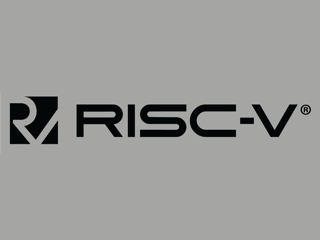
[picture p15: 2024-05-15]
software/emulator/sdcard/jpeg/rvgray.jpg

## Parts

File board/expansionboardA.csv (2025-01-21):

Id | Designator | Footprint | Quantity | Designation | Supplier and ref
1 | JTAG1 | PinHeader_1x06_P2.54mm_Vertical | 1 | Conn_01x06_Pin
2 | J1 | GCT_USB4085-GF-A_REVA4 | 1 | USB_C_Receptacle
3 | U3 | LTST-BILED-15X16 | 1 | LTST-C195KGJRKT
4 | tEN1,t3V3,t5V0,tPWR1 | TestPoint_Pad_D1.0mm | 4 | TestPoint
5 | R1 | R_0603_1608Metric_Pad0.98x0.95mm_HandSolder | 1 | 330Ohm
6 | VR1 | VREG_LM1117MPX-3.3_NOPB | 1 | LM1117MPX-3.3/NOPB
7 | U2 | PinSocket_2x32_P2.54mm_Vertical | 1 | GPIO_U2
8 | U4 | PinSocket_2x32_P2.54mm_Vertical | 1 | GPIO_U4
9 | C4,C5 | C_0603_1608Metric_Pad1.08x0.95mm_HandSolder | 2 | 0.1uf
10 | U1 | ESP32-S3-WROOM-1 | 1 | ESP32-S3-WROOM-1
11 | R6,R4,R3,R5,R2,R7 | R_0603_1608Metric_Pad0.98x0.95mm_HandSolder | 6 | 33Ohm
12 | D4,D5,D2,D1,D3 | LED_1206_3216Metric_Pad1.42x1.75mm_HandSolder | 5 | LED
13 | CRD1 | HRS_DM3AT-SF-PEJM5 | 1 | DM3AT-SF-PEJM5
14 | C6,C7 | C_0805_2012Metric_Pad1.18x1.45mm_HandSolder | 2 | 10uf
15 | J2 | MOLEX_2086581051 | 1 | 2086581051
16 | SW4 | SW_Tactile_SPST_NO_Straight_CK_PTS636Sx25SMTRLFS | 1 | ESPPROG

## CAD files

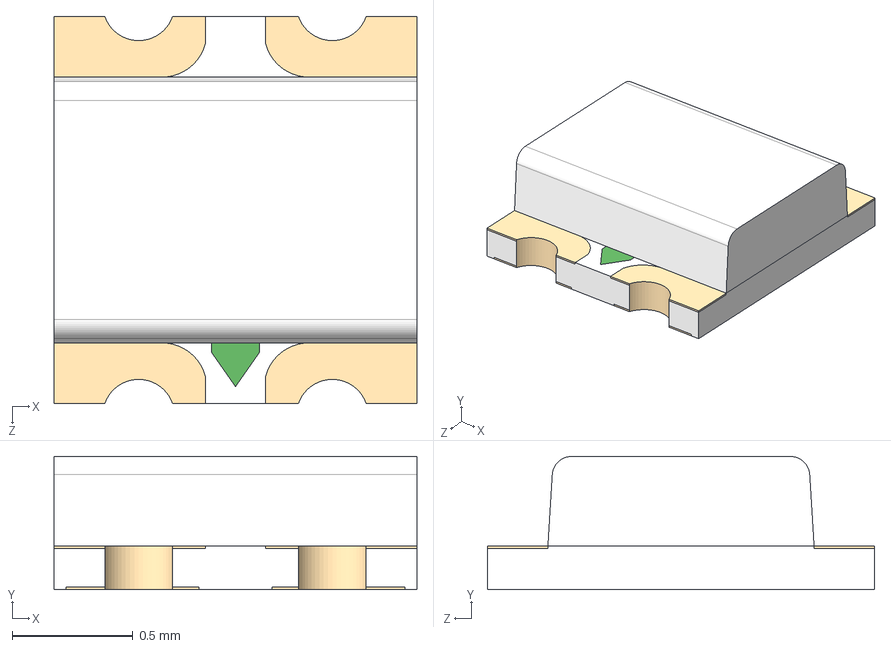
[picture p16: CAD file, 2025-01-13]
board/LTST_C195KGJRKT/LTST-C195KGJRKT.step
1.50 x 0.55 x 1.60 mm

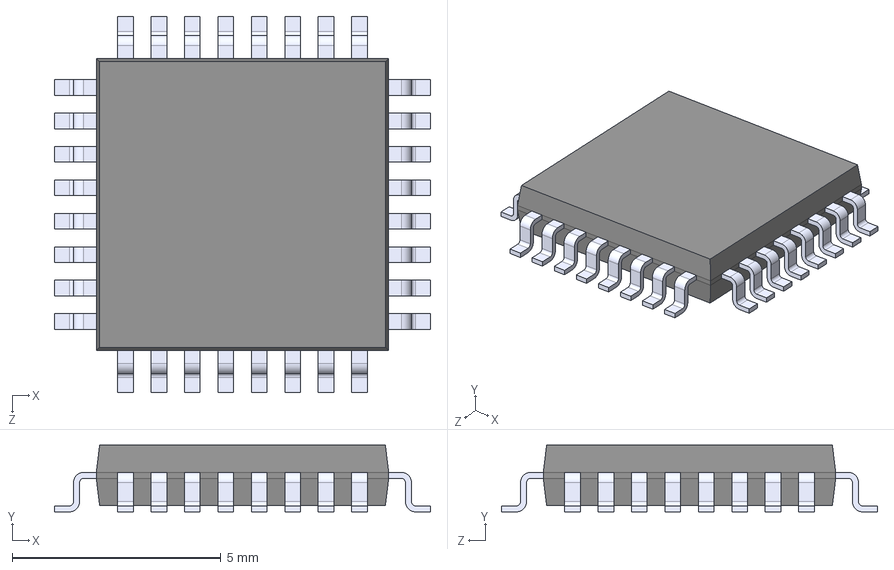
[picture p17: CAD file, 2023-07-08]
board/MAX3420EECJ/MAX3420EECJ_T.step
9.00 x 1.60 x 9.00 mm

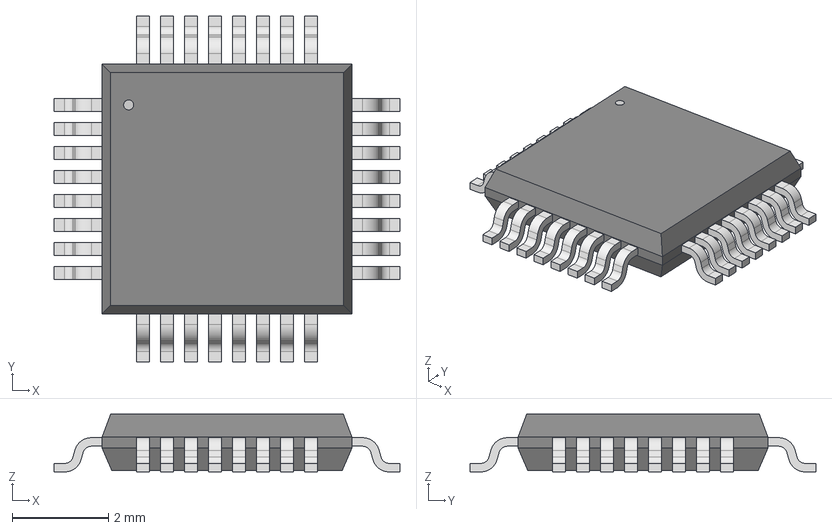
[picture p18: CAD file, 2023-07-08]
board/MAX3421EEHJ_T/21-0110-C_90-0149-32L_MXM.step
7.20 x 7.20 x 1.20 mm

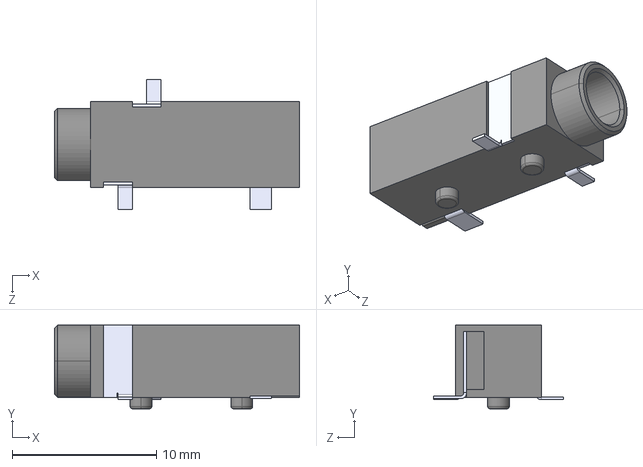
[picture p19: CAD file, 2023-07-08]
board/SJ-3523-SMT-TR/SJ-3523-SMT-TR.step
17.0 x 5.80 x 9.00 mm

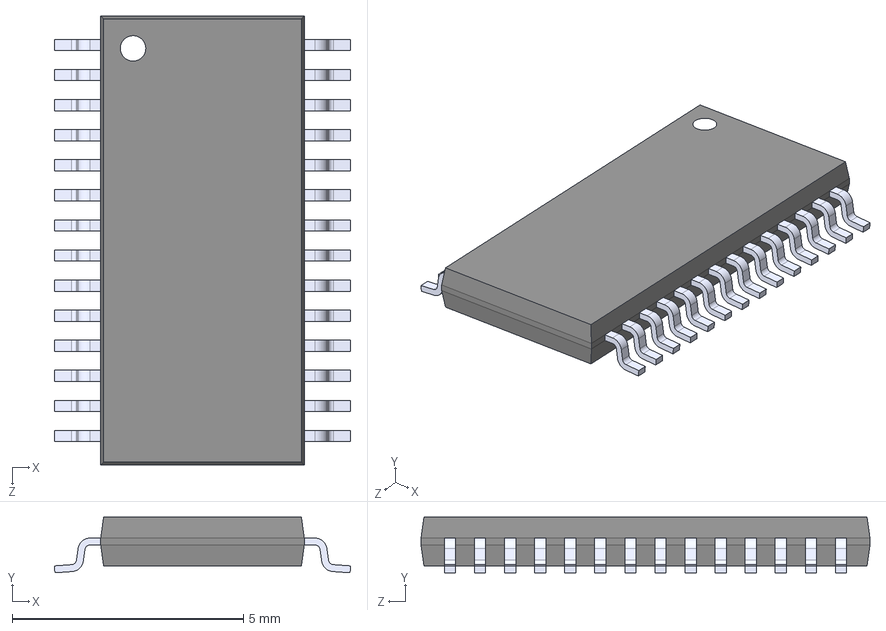
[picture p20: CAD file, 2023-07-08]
board/TLV320AIC23BIPW/TLV320AIC23BIPW.step
6.40 x 1.20 x 9.70 mm

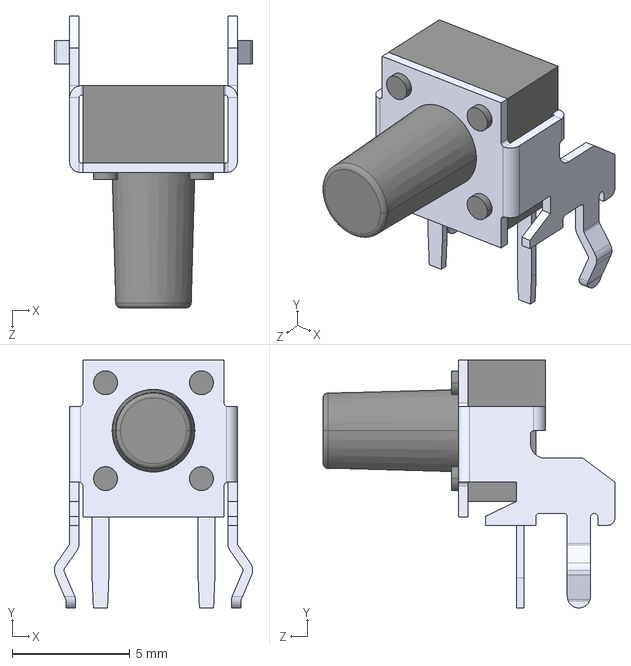
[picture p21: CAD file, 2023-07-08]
boardB/1_1825027_1/1-1825027-1.step
8.41 x 10.5 x 12.4 mm

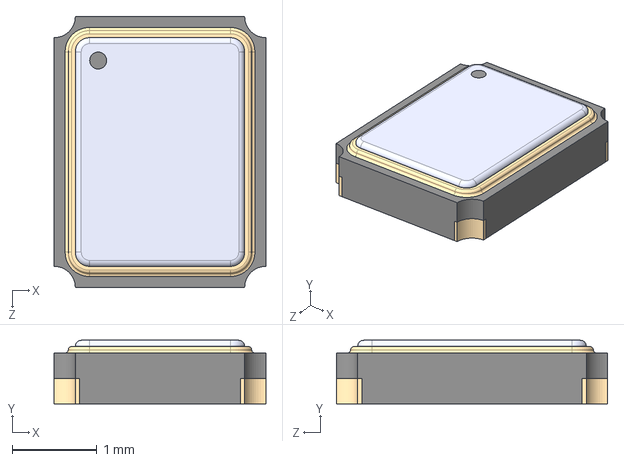
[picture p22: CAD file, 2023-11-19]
boardB/403C35D12M00000/403C35D12M00000.step
2.50 x 0.75 x 3.20 mm

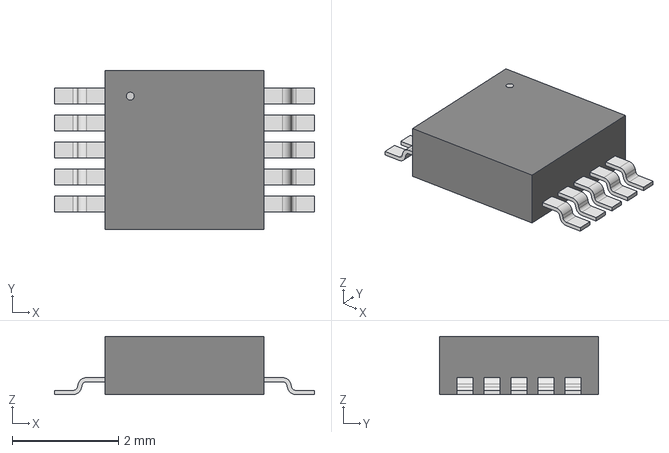
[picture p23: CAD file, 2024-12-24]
boardB/CS4344/CIR_3TSSOP-10.step
4.90 x 3.00 x 1.09 mm

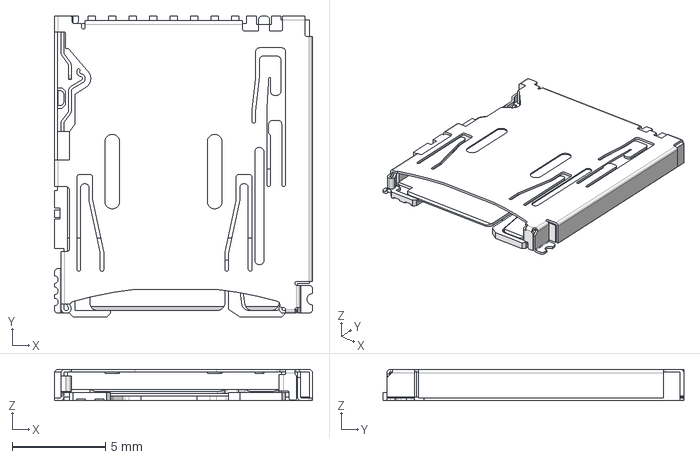
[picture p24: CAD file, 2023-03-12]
boardB/DM3AT-SF-PEJM5/DM3AT-SF-PEJM5.step
13.8 x 16.2 x 1.68 mm

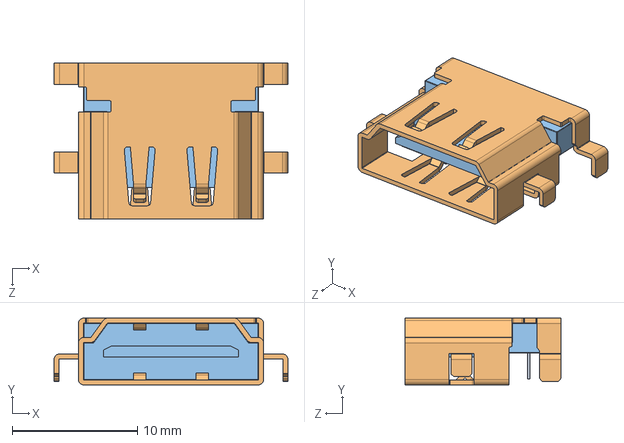
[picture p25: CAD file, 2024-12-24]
boardB/HD02-19-M-MSMT-TR/CUI_DEVICES_HD02-19-M-MSMT-TR.step
18.7 x 5.35 x 12.4 mm

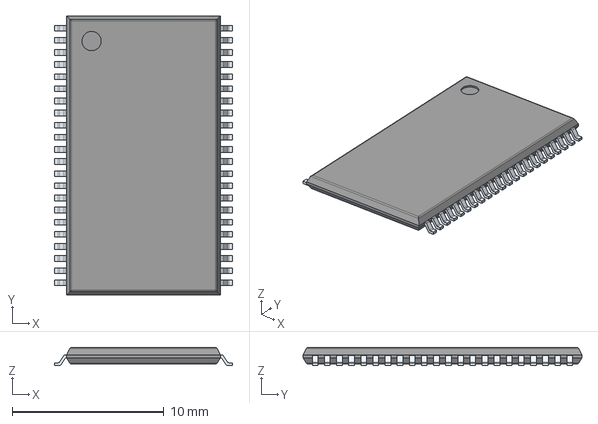
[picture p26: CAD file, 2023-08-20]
boardB/IS61WV25616EDBLL-10TLI/3D/IS61WV25616EDBLL-10TLI.stp
11.8 x 18.4 x 1.20 mm
PinsArrayLR

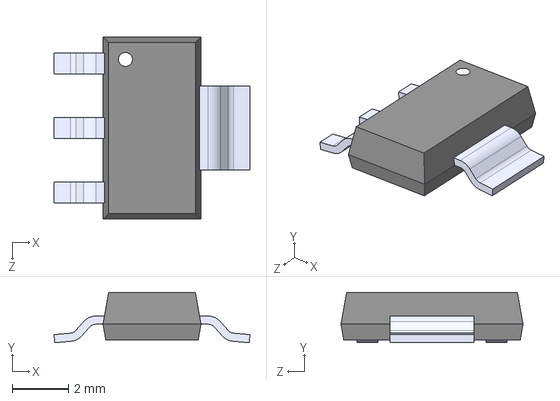
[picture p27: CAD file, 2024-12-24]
boardB/LM1117MPX33NOPB/LM1117MPX-3.3_NOPB.step
7.00 x 1.80 x 6.50 mm

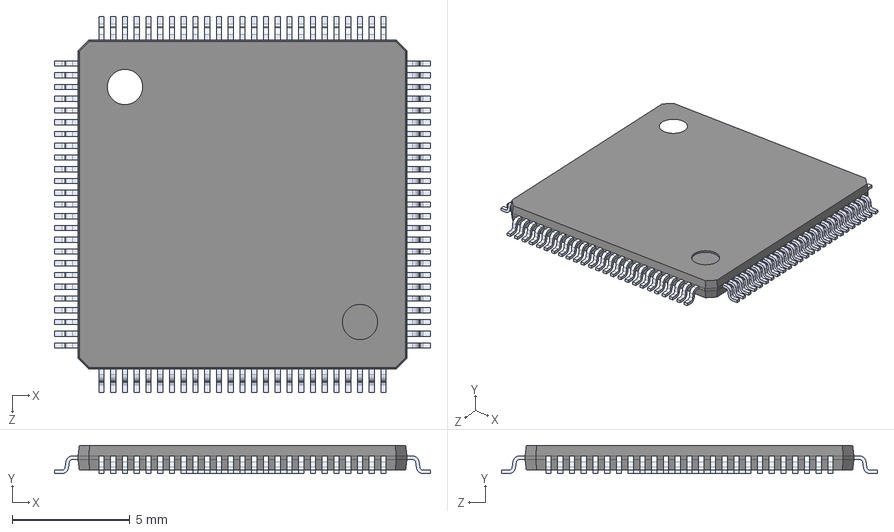
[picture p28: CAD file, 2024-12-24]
boardB/SII1136CTU/SII1136CTU.step
16.0 x 1.20 x 16.0 mm

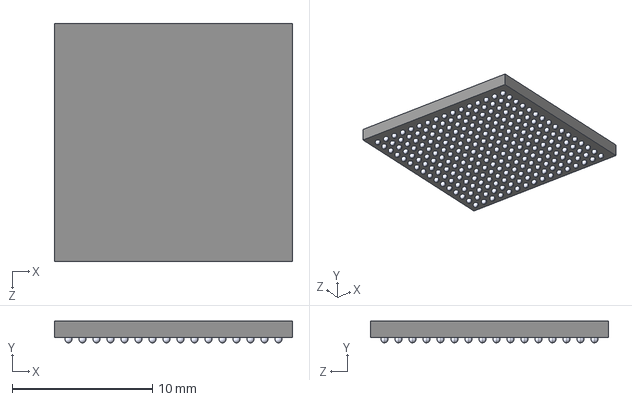
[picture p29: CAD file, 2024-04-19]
boardB/xc7a355ftg256c/XC7A35T-1FTG256C.STEP
17.0 x 1.55 x 17.0 mm

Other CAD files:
mechanical/expansionboardA.SLDASM
boardB/SJ-3523-SMT-TR/SJ-3523-SMT-TR.step
boardB/TLV320AIC23BIPW/TLV320AIC23BIPW.step
enclosure/enctop.SLDPRT
board/2086581051/2086581051.step
board/646430910/676430910.stp
board/AS01508MS-SC11-WP-R/AS01508MS-SC11-WP-R.step
board/CS4344/CIR_3TSSOP-10.step
board/DM3AT-SF-PEJM5/DM3AT-SF-PEJM5.step
board/HD02-19-M-MSMT-TR/CUI_DEVICES_HD02-19-M-MSMT-TR.step
board/LM1117MPX33NOPB/LM1117MPX-3.3_NOPB.step
board/MOLEX_676430910/676430910.stp
boardB/124020/12402012E212A.step
boardB/646430910/676430910.stp
boardB/AS01508MS-SC11-WP-R/AS01508MS-SC11-WP-R.step
boardB/MOLEX_676430910/676430910.stp
enclosure/encbottom.SLDPRT

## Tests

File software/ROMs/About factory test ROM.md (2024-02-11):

Factory test

This folder contains the firmware to load into the factory test module.
Its sole purpose is to use the onboard debug port and check to see if the
board powers up correctly, and executes code to emit a string on
the UART port.

Please do not use as a regular ROM image for the final device, it will not work and will break the system!

Thanks,
Engin Cilasun

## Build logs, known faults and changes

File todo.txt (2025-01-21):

[+] Horizontal blanking interrupt
[+] Work on file upload support via ESP32 GPIO
[+] Add remote reboot trigger via ESP32 GPIO
[ ] Add memory access exception (physical memory access)
[ ] Utilize the new JTAG connector to support debuger over OCD

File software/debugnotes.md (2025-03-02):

To start risc32-unknown-elf-gdb set up for our target architecture:
```
C:\riscv32-gcc\bin\riscv32-unknown-elf-gdb.exe
set debug remote 1
set architecture riscv:rv32
```

To start debugging on the the actual hardware:
```
target remote \\.\COM6
```

To start debugging on the emulator:
```
target remote localhost:1234
```

Then load your code to debug and wait for the upload to finish:
```
load samples/led/led.elf
```

Alternatively you can place the set/target/load commands into a file (for example gdbcmd) and instead use:
```
C:\riscv32-gcc\bin\riscv32-unknown-elf-gdb.exe -x gdbcmd
```

If you wish to load debug data for your executable you can also use:
```
C:\riscv32-gcc\bin\riscv32-unknown-elf-gdb.exe -x gdbcmd samples/mycode/mycode.elf
```

to make it easier to start debugging. See this folder for a sample gdbcmd file you can use to add your own setup.

Now you can debug your program as usual with GDB

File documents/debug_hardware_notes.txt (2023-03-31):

--------------------------------------------------------------------------------------
Notes:
--------------------------------------------------------------------------------------

[31:8] ? [7:0] field

need full access to:
GPR and CSR (r/w)
memory via CPU (r/w)
memory via AXI4 (r/w)
ebreak halts the CPU
single step executes one instruction only (no instruction merge)
debugger can halt/resume CPU
instruction buffer to execute short instruction sequences (optional)
PC, r/w address or instruction opcodes can be set as break condition (optional)

--------------------------------------------------------------------------------------
Connectivity:
--------------------------------------------------------------------------------------

Debug host runs gdb+openocd ->
    connects to debug transport (USB JTAG adapter) ->
    DTM (debug transport module) on device ->
    DMI (debug module interface) ->
    DM (debug module, can be more than one)

--------------------------------------------------------------------------------------
Implementation details
--------------------------------------------------------------------------------------

Fetch unit can be used to halt/resume the CPU or put it in debug mode.
It can also place the generic memory / register read&write requests.
To achieve this it'll have to read command requests from the DM and talk back via FIFOs.

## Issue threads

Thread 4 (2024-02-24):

Work on unaligned and masked DMA

ecilasun, 2024-02-24:
Source has to be 16 byte aligned, but target can be misaligned.
This is going to be mostly useful for moving masked graphics (sprites or maps) around with a bit of CPU and VPU scan-out pointer assistance.

Closed 2024-11-01.

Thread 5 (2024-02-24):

Vertical (and/or horizontal?) blanking interrupt support

ecilasun, 2024-02-24:
This is a bit tricky since we already have several interrupt sources on the device, but would be interesting to see.
Alternatively, a very precise timer interrupt with high priority might do the trick.

ecilasun, 2024-05-04:
Might be able to limit these interrupts to the non-OS core, will investigate further.

Closed 2024-10-27.

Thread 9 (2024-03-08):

Board has to support both the barrel power connector and USB-C with a simple switch

ecilasun, 2024-03-08:
Make sure there's an onboard switch to toggle between USB-C power and external power (5V+) on next board revision.

ecilasun, 2024-04-28:
NOTE: This will not be an issue on the next board version where the FPGA is part of the board.

Closed 2024-10-27.

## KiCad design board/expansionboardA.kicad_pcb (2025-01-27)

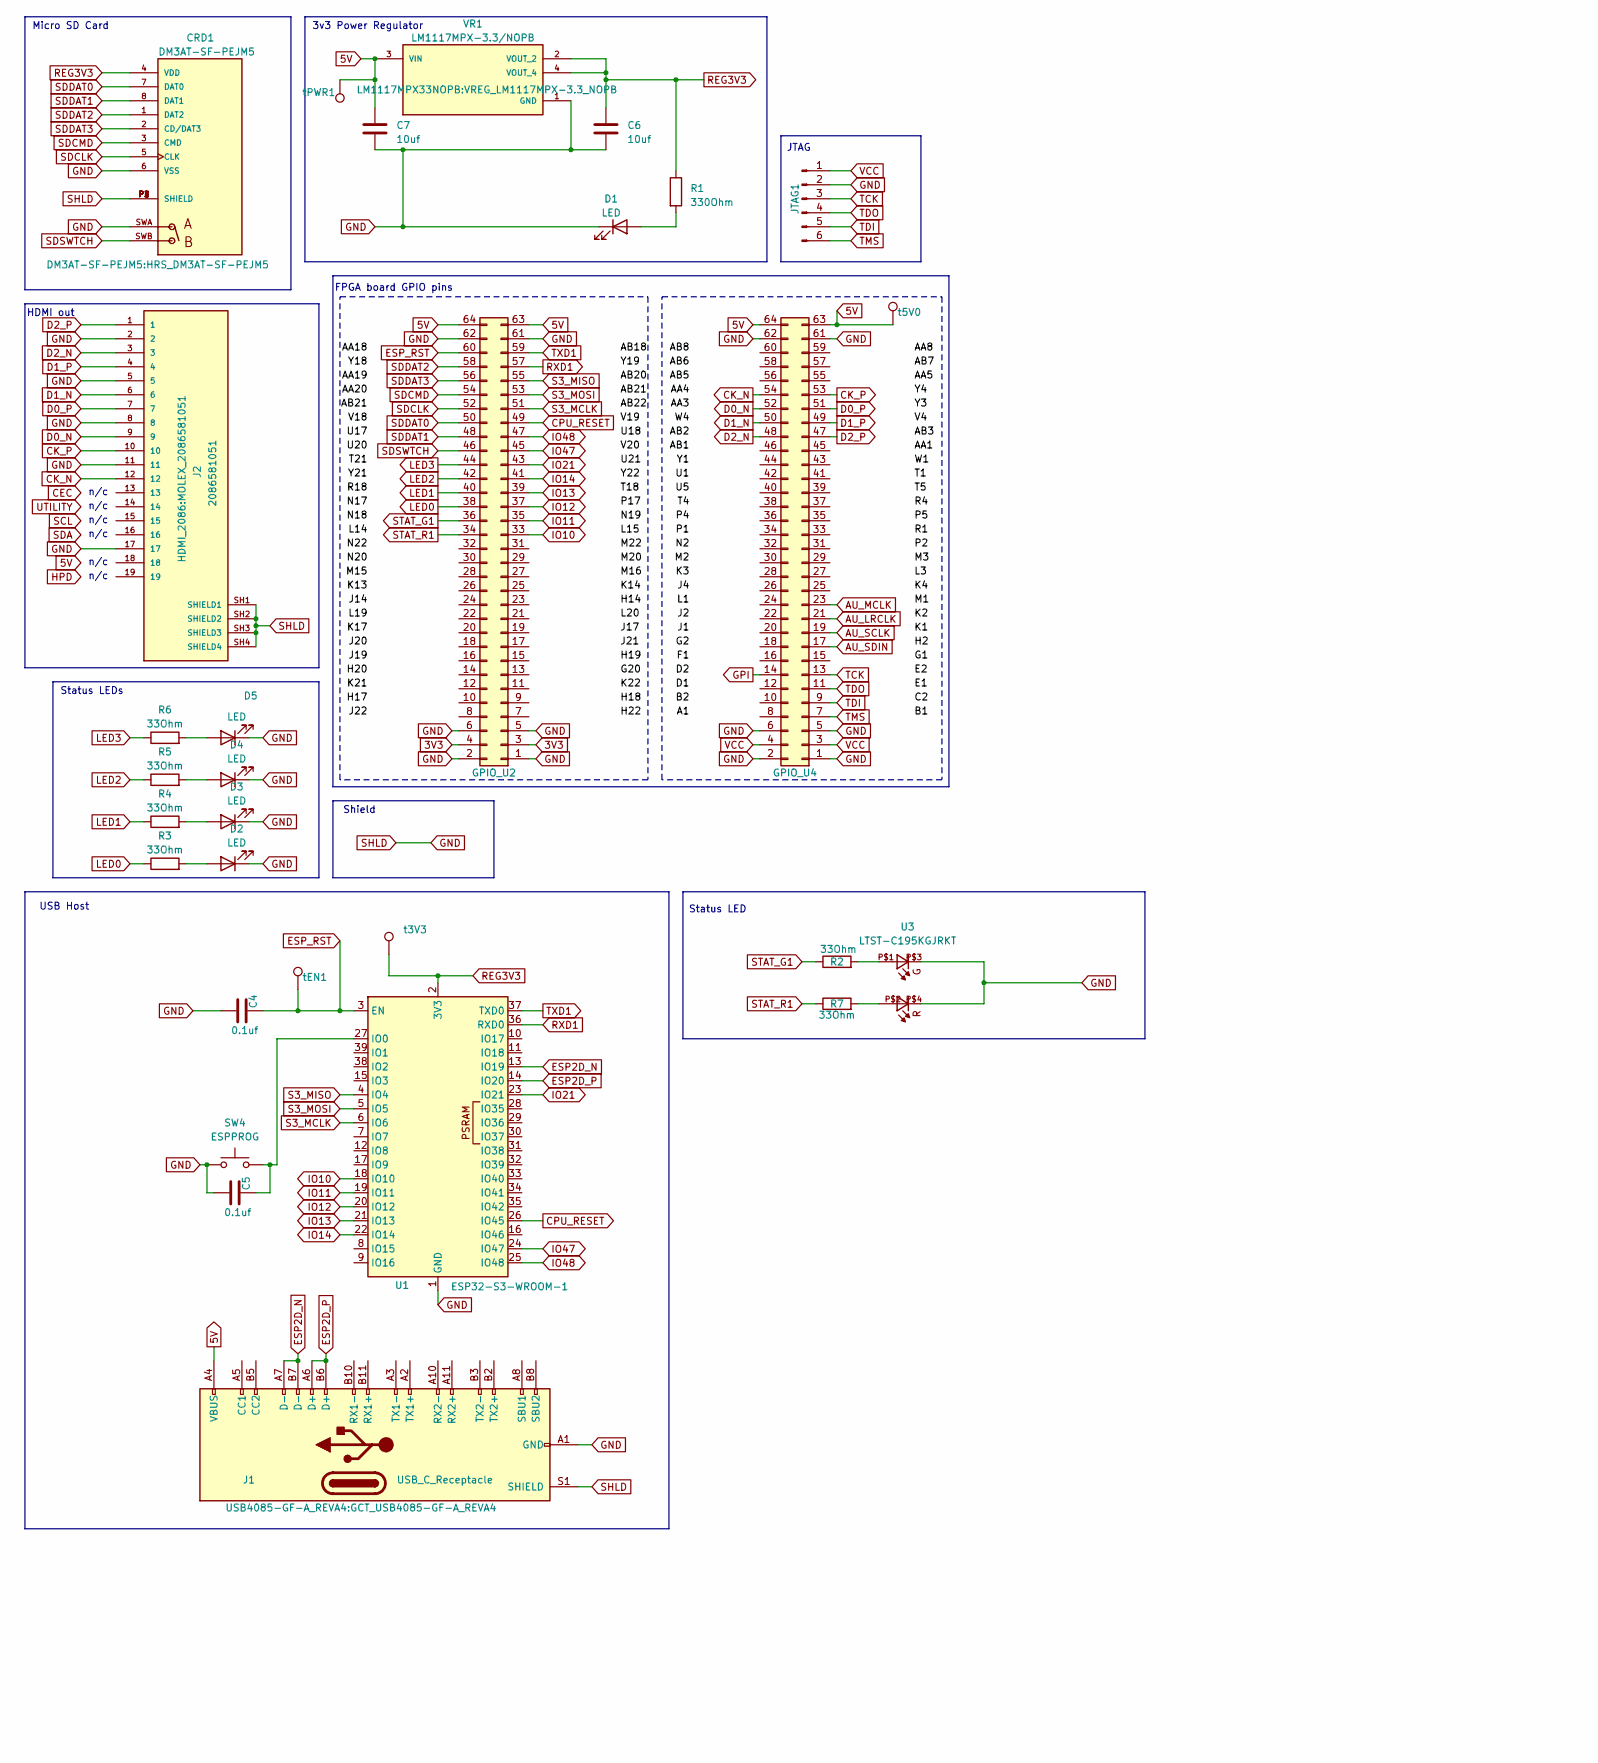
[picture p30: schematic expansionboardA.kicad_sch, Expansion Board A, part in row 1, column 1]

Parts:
C4, C5: 0.1uf; C_0603_1608Metric_Pad1.08x0.95mm_HandSolder
C6, C7: 10uf; C_0805_2012Metric_Pad1.18x1.45mm_HandSolder
CRD1: DM3AT-SF-PEJM5; HRS_DM3AT-SF-PEJM5
D1, D2, D3, D4, D5: LED; LED_1206_3216Metric_Pad1.42x1.75mm_HandSolder
J1: USB_C_Receptacle; GCT_USB4085-GF-A_REVA4
J2: 2086581051; MOLEX_2086581051; PARTREV A
JTAG1: Conn_01x06_Pin; PinHeader_1x06_P2.54mm_Vertical
R1: 330Ohm; R_0603_1608Metric_Pad0.98x0.95mm_HandSolder
R2, R3, R4, R5, R6, R7: 33Ohm; R_0603_1608Metric_Pad0.98x0.95mm_HandSolder
SW4: ESPPROG; SW_Tactile_SPST_NO_Straight_CK_PTS636Sx25SMTRLFS
U1: ESP32-S3-WROOM-1
U2: GPIO_U2; PinSocket_2x32_P2.54mm_Vertical
U3: LTST-C195KGJRKT; LTST-BILED-15X16
U4: GPIO_U4; PinSocket_2x32_P2.54mm_Vertical
VR1: LM1117MPX-3.3/NOPB; VREG_LM1117MPX-3.3_NOPB; PARTREV O
t3V3, t5V0: TestPoint; TestPoint_Pad_D1.0mm
tEN1: TestPoint; TestPoint_Pad_D1.0mm
tPWR1: TestPoint; TestPoint_Pad_D1.0mm

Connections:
3V3: U2.3, U2.4
5V: C7.1, J1.A4 (VBUS), J1.A9 (VBUS), J1.B4 (VBUS), J1.B9 (VBUS), U2.63, U2.64, U4.63, U4.64, VR1.3 (VIN), t5V0.1, tPWR1.1
AU_LRCLK: U4.21
AU_MCLK: U4.23
AU_SCLK: U4.19
AU_SDIN: U4.17
CK_N: J2.12, U4.54
CK_P: J2.10, U4.53
CPU_RESET: U1.26 (IO45), U2.49
D0_N: J2.9, U4.52
D0_P: J2.7, U4.51
D1_N: J2.6, U4.50
D1_P: J2.4, U4.49
D2_N: J2.3, U4.48
D2_P: J2.1, U4.47
ESP2D_N: J1.A7 (D-), J1.B7 (D-), U1.13 (IO19)
ESP2D_P: J1.A6 (D+), J1.B6 (D+), U1.14 (IO20)
ESP_RST: C4.1, U1.3 (EN), U2.60, tEN1.1
GND: C4.2, C5.2, C6.2, C7.2, CRD1.6 (VSS), CRD1.P1 (SHIELD), CRD1.P2 (SHIELD), CRD1.P3 (SHIELD), CRD1.P4 (SHIELD), CRD1.SWA, D1.1 (K), D2.1 (K), D3.1 (K), D4.1 (K), D5.1 (K), J1.A1 (GND), J1.A12 (GND), J1.B1 (GND), J1.B12 (GND), J1.S1 (SHIELD), J2.2, J2.5, J2.8, J2.11, J2.17, J2.SH1 (SHIELD1), J2.SH2 (SHIELD2), J2.SH3 (SHIELD3), J2.SH4 (SHIELD4), JTAG1.2, SW4.1, U1.1 (GND), U1.40 (GND), U1.41 (GND), U2.1, U2.2, U2.5, U2.6, U2.61, U2.62, U3.P$3, U3.P$4, U4.1, U4.2, U4.5, U4.6, U4.61, U4.62, VR1.1 (GND)
GPI: U4.14
IO10: U1.18 (IO10), U2.33
IO11: U1.19 (IO11), U2.35
IO12: U1.20 (IO12), U2.37
IO13: U1.21 (IO13), U2.39
IO14: U1.22 (IO14), U2.41
IO21: U1.23 (IO21), U2.43
IO47: U1.24 (IO47), U2.45
IO48: U1.25 (IO48), U2.47
LED0: R3.1, U2.38
LED1: R4.1, U2.40
LED2: R5.1, U2.42
LED3: R6.1, U2.44
unnamed: D1.2 (A), R1.2
unnamed: D2.2 (A), R3.2
unnamed: D3.2 (A), R4.2
unnamed: D4.2 (A), R5.2
unnamed: D5.2 (A), R6.2
unnamed: R2.2, U3.P$1
unnamed: R7.2, U3.P$2
unnamed: C5.1, SW4.2, U1.27 (IO0)
REG3V3: C6.1, CRD1.4 (VDD), R1.1, U1.2 (3V3), VR1.2 (VOUT_2), VR1.4 (VOUT_4), t3V3.1
RXD1: U1.36 (RXD0), U2.57
S3_MCLK: U1.6 (IO6), U2.51
S3_MISO: U1.4 (IO4), U2.55
S3_MOSI: U1.5 (IO5), U2.53
SDCLK: CRD1.5 (CLK), U2.52
SDCMD: CRD1.3 (CMD), U2.54
SDDAT0: CRD1.7 (DAT0), U2.50
SDDAT1: CRD1.8 (DAT1), U2.48
SDDAT2: CRD1.1 (DAT2), U2.58
SDDAT3: CRD1.2 (CD/DAT3), U2.56
SDSWTCH: CRD1.SWB, U2.46
STAT_G1: R2.1, U2.36
STAT_R1: R7.1, U2.34
TCK: JTAG1.3, U4.13
TDI: JTAG1.5, U4.9
TDO: JTAG1.4, U4.11
TMS: JTAG1.6, U4.7
TXD1: U1.37 (TXD0), U2.59
VCC: JTAG1.1, U4.3, U4.4

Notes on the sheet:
n/c
FPGA board GPIO pins
Micro SD Card
JTAG
Status LED
Status LEDs
USB Host
Shield
3v3 Power Regulator
HDMI out

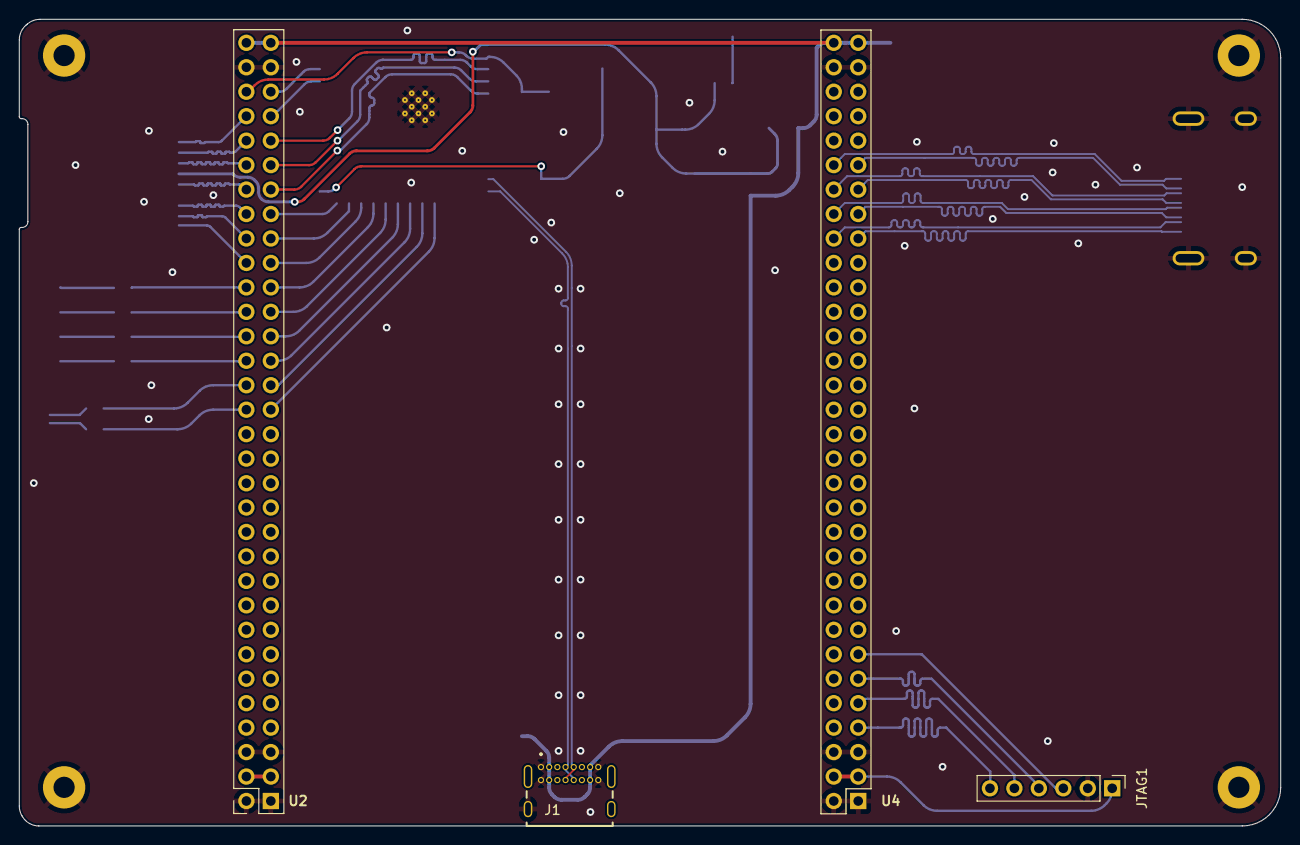
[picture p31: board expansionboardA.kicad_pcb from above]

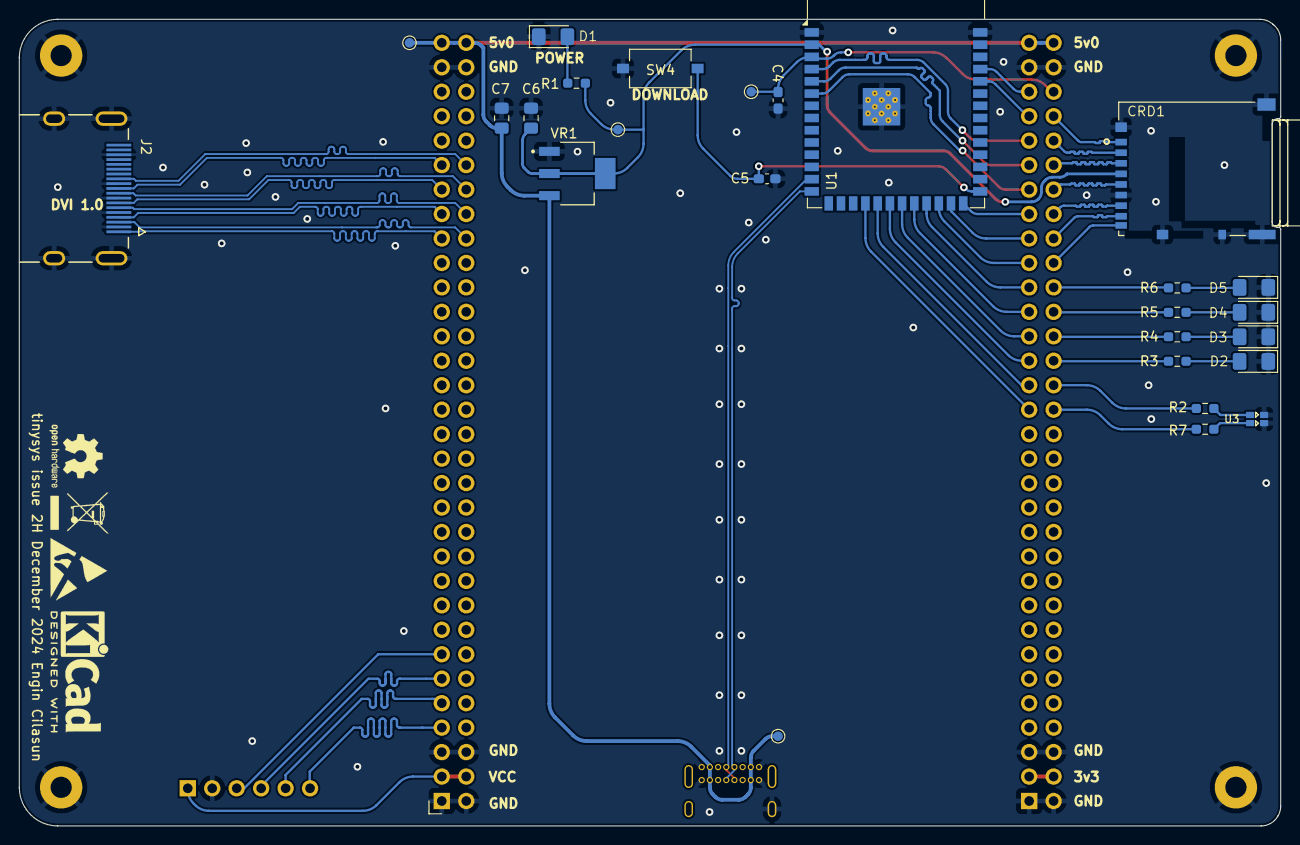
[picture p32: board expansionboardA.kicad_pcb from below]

Board: 2 copper layers, 131.0 x 83.8 mm, 30 parts (28 on the bottom side), 55 nets.

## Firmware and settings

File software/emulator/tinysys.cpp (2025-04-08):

#include "tinysys.h"

static socket_t newsockfd;

static const char* emulatorVersionString = "tinysys emulator v0.7";

static int AudioQueueCapacity = 1024;	// Size of the audio queue in samples
const int QueueSampleCount = 64;		// Push this many samples to the queue per iteration
static int AudioQueueCapacityInBytes = AudioQueueCapacity*sizeof(uint16_t)*2;
const int QueueSampleByteSize = QueueSampleCount*sizeof(int16_t)*2;

static TTF_Font* s_debugfont = nullptr;
static SDL_Surface* s_textSurface = nullptr;
static uint32_t s_logotime = 0;

#if defined(CPU_STATS)
static SDL_Surface* s_statSurface = nullptr;
#endif

const int WIDTH = 640;
const int HEIGHT = 480;

struct EmulatorContext
{
	CEmulator* emulator{ nullptr };
	SDL_Window* window{ nullptr };
	SDL_Surface* compositesurface{ nullptr };
	SDL_GameController* gamecontroller{ nullptr };
};

static bool s_alive = true;
static uint64_t s_wallclock = 0;

#if defined(GALLIFREY)
int emulatorthreadcpu0(void* data)
{
	SDL_SetThreadPriority(SDL_THREAD_PRIORITY_NORMAL);

	EmulatorContext* ctx = (EmulatorContext*)data;
	int spins = 0;
	do
	{
		CEmulator *emulator = ctx->emulator;
		if (emulator->m_debugStop)
		{
			// Stop for debugger
			emulator->m_debugAck = 1;
		}
		else
		{
			emulator->m_debugAck = 0;
			emulator->Step(s_wallclock, 0);
		}

		if (spins % 1048576 == 0)
		{
			// Handle hardware switch etc changes
			emulator->m_bus->GetSDCard()->UpdateSDCardSwitch();
		}
		++spins;
	} while(s_alive);

	return 0;
}

int emulatorthreadcpu1(void* data)
{
	SDL_SetThreadPriority(SDL_THREAD_PRIORITY_NORMAL);

	EmulatorContext* ctx = (EmulatorContext*)data;
	do
	{
		CEmulator *emulator = ctx->emulator;
		emulator->Step(s_wallclock, 1);
	} while(s_alive);

	return 0;
}
#else
int emulatorthread(void* data)
{
	SDL_SetThreadPriority(SDL_THREAD_PRIORITY_NORMAL);

	EmulatorContext* ctx = (EmulatorContext*)data;
	int spins = 0;
	do
	{
		CEmulator *emulator = ctx->emulator;
		if (emulator->m_debugStop)
		{
			// Stop for debugger
			emulator->m_debugAck = 1;
		}
		else
		{
			emulator->m_debugAck = 0;
			emulator->Step(s_wallclock, 0);
			emulator->Step(s_wallclock, 1);
		}

		if (spins % 1048576 == 0)
		{
			// Handle hardware switch etc changes
			emulator->m_bus->GetSDCard()->UpdateSDCardSwitch();
		}
		++spins;
	} while(s_alive);

	return 0;
}
#endif

int audiothread(void* data)
{
	SDL_SetThreadPriority(SDL_THREAD_PRIORITY_LOW);

	CEmulator* emulator = (CEmulator*)data;
	uint32_t pastSelector = 0xFF;
	CAPU *apu = emulator->m_bus->GetAPU();
	int queueReadCursor = 0;
	uint32_t *tmpbuf = new uint32_t[QueueSampleCount*8];
	int spaceLeft = AudioQueueCapacityInBytes;
	do
	{
		if (apu->m_rateselector != pastSelector)
		{
			pastSelector = apu->m_rateselector;
			SDL_PauseAudioDevice(emulator->m_audioDevice, pastSelector ? 0 : 1);
		}

		// Check if we've got enough space in the audio queue to fit our 128 samples
		if (pastSelector && (spaceLeft >= QueueSampleByteSize))
		{
			uint8_t* source = ((uint8_t*)apu->GetPlaybackData()) + queueReadCursor;

			// Queue more samples if we found some room
			if (pastSelector == 4)			// 44.1kHz
			{
				SDL_QueueAudio(emulator->m_audioDevice, source, QueueSampleByteSize);
				queueReadCursor += QueueSampleByteSize;
			}
			else if (pastSelector == 2)		// 22.05kHz
			{
				uint16_t* p = (uint16_t*)source;
				for (int i = 0; i < QueueSampleCount/2; i++)
				{
					uint16_t L = p[i * 2 + 0];
					uint16_t R = p[i * 2 + 1];
					tmpbuf[i * 2 + 0] = R<<16 | L;
					tmpbuf[i * 2 + 1] = R<<16 | L;
				}
				SDL_QueueAudio(emulator->m_audioDevice, tmpbuf, QueueSampleByteSize);
				queueReadCursor += QueueSampleByteSize/2;
			}
			else if (pastSelector == 1)		// 11.025kHz
			{
				uint16_t* p = (uint16_t*)source;
				for (int i = 0; i < QueueSampleCount/4; i++)
				{
					uint16_t L = p[i * 2 + 0];
					uint16_t R = p[i * 2 + 1];
					tmpbuf[i * 4 + 0] = R<<16 | L;
					tmpbuf[i * 4 + 1] = R<<16 | L;
					tmpbuf[i * 4 + 2] = R<<16 | L;
					tmpbuf[i * 4 + 3] = R<<16 | L;
				}
				SDL_QueueAudio(emulator->m_audioDevice, tmpbuf, QueueSampleByteSize);
				queueReadCursor += QueueSampleByteSize/4;
			}
			// else if (pastSelector == 0) {} // audio is paused
		}

		// Bytes queued reached APU word count, swap
		if (queueReadCursor >= apu->m_apuwordcount*sizeof(int32_t))
		{
			queueReadCursor = 0;
			apu->FlipBuffers();
		}

		if (pastSelector)
		{
			int bytesQueued = SDL_GetQueuedAudioSize(emulator->m_audioDevice);
			spaceLeft = AudioQueueCapacityInBytes-bytesQueued;
		}
		else
			spaceLeft = AudioQueueCapacityInBytes;
	} while(s_alive);

	delete [] tmpbuf;

	return 0;
}

float Clamp(float value, float min, float max)
{
	if (value < min)
		return min;
	if (value > max)
		return max;
	return value;
}

void ClampAnalogInput(Axis6& input, float innerDeadzone, float outerDeadzone)
{
	float magleft = input.leftx*input.leftx + input.lefty*input.lefty;
	float magright = input.rightx*input.rightx + input.righty*input.righty;

	if (magleft == 0.f)
	{
		input.leftx = 0;
		input.lefty = 0;
	}
	else
	{
		magleft = sqrtf(magleft);
		float scale = (magleft - innerDeadzone) / (outerDeadzone - innerDeadzone);
		input.leftx = input.leftx * Clamp(scale, 0, 1) / magleft;
		input.lefty = input.lefty * Clamp(scale, 0, 1) / magleft;
	}

	if (magright == 0.f)
	{
		input.rightx = 0;
		input.righty = 0;
	}
	else
	{
		magright = sqrtf(magright);
		float scale = (magright - innerDeadzone) / (outerDeadzone - innerDeadzone);
		input.rightx = input.rightx * Clamp(scale, 0, 1) / magright;
		input.righty = input.righty * Clamp(scale, 0, 1) / magright;
	}

	input.lefttrigger = Clamp(input.lefttrigger, 0, 1);
	input.righttrigger = Clamp(input.righttrigger, 0, 1);
}

void ControllerAdd(EmulatorContext& ctx)
{
	int numJoy = SDL_NumJoysticks();
	if (numJoy <= 0)
		fprintf(stderr, "No joysticks: %d\n", numJoy);
	else
		fprintf(stderr, "Found %d joysticks\n", numJoy);

	for (int i = 0; i < numJoy; ++i)
	{
		if (SDL_IsGameController(i))
		{
			ctx.gamecontroller = SDL_GameControllerOpen(i);
			if (ctx.gamecontroller)
			{
				if (SDL_GameControllerGetAttached(ctx.gamecontroller))
				{
					fprintf(stderr, "Using game controller #%d: '%s'\n", i, SDL_GameControllerName(ctx.gamecontroller));
					// Read button mappings
					for (int j = 0; j < SDL_CONTROLLER_BUTTON_MAX; ++j)
					{
						if (SDL_GameControllerHasButton(ctx.gamecontroller, (SDL_GameControllerButton)j))
						{
							SDL_GameControllerButtonBind bind = SDL_GameControllerGetBindForButton(ctx.gamecontroller, (SDL_GameControllerButton)j);
							switch (bind.bindType)
							{
								case SDL_CONTROLLER_BINDTYPE_BUTTON:
									fprintf(stderr, "Button %d: %s\n", j, SDL_GameControllerGetStringForButton((SDL_GameControllerButton)j));
								break;
								case SDL_CONTROLLER_BINDTYPE_AXIS:
									fprintf(stderr, "Axis %d: %s\n", j, SDL_GameControllerGetStringForButton((SDL_GameControllerButton)j));
								break;
								case SDL_CONTROLLER_BINDTYPE_HAT:
									fprintf(stderr, "Hat %d: %s\n", j, SDL_GameControllerGetStringForButton((SDL_GameControllerButton)j));
								break;
								default:
								{
									fprintf(stderr, "Unknown %d: %s\n", j, SDL_GameControllerGetStringForButton((SDL_GameControllerButton)j));
								}
							}
						}
					}
					break;
				}
			}
		}
	}
}

void ControllerRemove(EmulatorContext& ctx)
{
	if (ctx.gamecontroller)
	{
		SDL_GameControllerClose(ctx.gamecontroller);
		ctx.gamecontroller = nullptr;
	}
}

uint32_t videoCallback(Uint32 interval, void* param)
{
	EmulatorContext* ctx = (EmulatorContext*)param;

	if (SDL_MUSTLOCK(ctx->compositesurface))
		SDL_LockSurface(ctx->compositesurface);

	uint32_t* pixels = (uint32_t*)ctx->compositesurface->pixels;

	ctx->emulator->UpdateVideoLink(pixels, ctx->compositesurface->pitch);

	uint32_t W = ctx->compositesurface->w;
	uint32_t H = ctx->compositesurface->h-8;
	uint32_t S = ctx->emulator->m_bus->GetLEDs()->m_ledstate;

	// TODO: LED image instead of flat colors
	{
		uint32_t L1 = S&0x1 ?  0xFFFF0000 : 0xFF200000; // status RED
		uint32_t L2 = S&0x2 ?  0xFF00FF00 : 0xFF002000; // status GREEN
		uint32_t L1_2 = L1 | L2;

		uint32_t L3 = S&0x4 ?  0xFFFF7F00 : 0xFF201000; // Debug EMBER
		uint32_t L4 = S&0x8 ?  0xFFFF7F00 : 0xFF201000;
		uint32_t L5 = S&0x10 ?  0xFFFF7F00 : 0xFF201000;
		uint32_t L6 = S&0x20 ?  0xFFFF7F00 : 0xFF201000;
		
		for (uint32_t j = H; j < H+8; j++)
		{
			for (uint32_t i = 8; i < 16; i++)
			{
				pixels[W*j+i] = L1_2;
				pixels[W*j+i+9] = L3;
				pixels[W*j+i+18] = L4;
				pixels[W*j+i+27] = L5;
				pixels[W*j+i+36] = L6;
			}
		}
	}

	// Center the splash image
	SDL_Rect splashRect = s_textSurface ? s_textSurface->clip_rect : SDL_Rect();
	splashRect.x = (W-splashRect.w)/2;
	splashRect.y = (H-splashRect.h)/2;

	// Stay up for 2 seconds
	if (s_logotime < 120)
	{
		int m = 0;
		int top = splashRect.y-4;
		int bottom = splashRect.y+splashRect.h+4;
		int d = bottom-top;
		for (int j = top; j < bottom; j++)
		{
			m = 255*(j-top)/d;
			for (uint32_t i = 0; i < W; i++)
				pixels[W*j+i] = 0xFF000000 | (m);
		}
	}

	if (SDL_MUSTLOCK(ctx->compositesurface))
		SDL_UnlockSurface(ctx->compositesurface);

	if (s_logotime < 120 && s_textSurface)
		SDL_BlitSurface(s_textSurface, nullptr, ctx->compositesurface, &splashRect);

	++s_logotime;

#if defined(CPU_STATS)
	if (s_statSurface)
	{
		SDL_Rect statRect = s_statSurface->clip_rect;
		statRect.y = H - (statRect.h+4);

		SDL_BlitSurface(s_statSurface, nullptr, ctx->compositesurface, &statRect);
	}
#endif

	// Update window surface
	SDL_BlitScaled(ctx->compositesurface, nullptr, SDL_GetWindowSurface(ctx->window), nullptr);
	SDL_UpdateWindowSurface(ctx->window);

	return interval;
}

// Print CPU stats
#if defined(CPU_STATS)
uint32_t statsCallback(Uint32 interval, void* param)
{
	EmulatorContext* ctx = (EmulatorContext*)param;
	char stats[768];

	CRV32 *cpu0 = ctx->emulator->m_cpu[0];
	snprintf(stats, 768, "CPU0\n");
	snprintf(stats, 768, "%sI$  read hits / misses: %d / %d\n", stats, cpu0->m_icache.m_hits, cpu0->m_icache.m_misses);
	snprintf(stats, 768, "%sEX retired instructions: %lld\n", stats, cpu0->m_retired);
	snprintf(stats, 768, "%sEX conditional branches taken / not taken: %d / %d\n", stats, cpu0->m_btaken, cpu0->m_bntaken);
	snprintf(stats, 768, "%sEX unconditional branches taken: %d\n", stats, cpu0->m_ucbtaken);
	snprintf(stats, 768, "%sD$  read hits / misses: %d / %d\n", stats, cpu0->m_dcache.m_readhits, cpu0->m_dcache.m_readmisses);
	snprintf(stats, 768, "%s   write hits / misses: %d / %d\n", stats, cpu0->m_dcache.m_writehits, cpu0->m_dcache.m_writemisses);

	CRV32 *cpu1 = ctx->emulator->m_cpu[1];
	snprintf(stats, 768, "%s\nCPU1\n", stats);
	snprintf(stats, 768, "%sI$  read hits / misses: %d / %d\n", stats, cpu1->m_icache.m_hits, cpu1->m_icache.m_misses);
	snprintf(stats, 768, "%sEX retired instructions: %lld\n", stats, cpu1->m_retired);
	snprintf(stats, 768, "%sEX conditional branches taken / not taken: %d / %d\n", stats, cpu1->m_btaken, cpu1->m_bntaken);
	snprintf(stats, 768, "%sEX unconditional branches taken: %d\n", stats, cpu1->m_ucbtaken);
	snprintf(stats, 768, "%sD$  read hits / misses: %d / %d\n", stats, cpu1->m_dcache.m_readhits, cpu1->m_dcache.m_readmisses);
	snprintf(stats, 768, "%s   write hits / misses: %d / %d\n", stats, cpu1->m_dcache.m_writehits, cpu1->m_dcache.m_writemisses);

	if (s_statSurface)
		SDL_FreeSurface(s_statSurface);
	s_statSurface = TTF_RenderText_Blended_Wrapped(s_debugfont, stats, {255,0,0}, WIDTH);

	cpu0->m_icache.m_hits = 0;
	cpu0->m_icache.m_misses = 0;
	cpu0->m_dcache.m_readhits = 0;
	cpu0->m_dcache.m_readmisses = 0;
	cpu0->m_dcache.m_writehits = 0;
	cpu0->m_dcache.m_writemisses = 0;
	cpu0->m_retired = 0;
	cpu0->m_btaken = 0;
	cpu0->m_bntaken = 0;
	cpu0->m_ucbtaken = 0;

	cpu1->m_icache.m_hits = 0;
	cpu1->m_icache.m_misses = 0;
	cpu1->m_dcache.m_readhits = 0;
	cpu1->m_dcache.m_readmisses = 0;
	cpu1->m_dcache.m_writehits = 0;
	cpu1->m_dcache.m_writemisses = 0;
	cpu1->m_retired = 0;
	cpu1->m_btaken = 0;
	cpu1->m_bntaken = 0;
	cpu1->m_ucbtaken = 0;

	return interval;
}
#endif

void gdbstubprocess(socket_t gdbsocket, CEmulator* emulator, char* buffer, int n)
{
	// Check the first character of the buffer to determine the packet type
	switch (buffer[0])
	{
		case '+':
			// ACK packet
			//gdbresponseack(gdbsocket);
			break;
		case '-':
			// NACK packet
			break;
		case 0x03:
			// Interrupt packet, do not shift buffer
			gdbprocesscommand(gdbsocket, emulator, buffer);
			break;
		case '$':
			// Command packet
			buffer++;
			gdbprocesscommand(gdbsocket, emulator, buffer);
			break;
		default:
			// Unknown packet
			break;
	}
}

int gdbstubthread(void* data)
{
	SDL_SetThreadPriority(SDL_THREAD_PRIORITY_LOW);

	EmulatorContext* ctx = (EmulatorContext*)data;

#ifdef CAT_WINDOWS
	WSADATA wsaData;
	int wsaerr;
	WORD wVersionRequested = MAKEWORD(2, 2);
	wsaerr = WSAStartup(wVersionRequested, &wsaData);
#endif

	// Create a socket
	socket_t sockfd = socket(AF_INET, SOCK_STREAM, IPPROTO_TCP);
	if (sockfd < 0)
	{
		fprintf(stderr, "Error opening socket\n");
		return -1;
	}
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
int main(int argc, char** argv)
#else
int SDL_main(int argc, char** argv)
#endif
{
	EmulatorContext ectx;
	ectx.emulator = new CEmulator;
	bool success;

	fprintf(stderr, "tinysys emulator v1.1E\n");

	const uint32_t resetvector = 0x0FFE0000;
	char bootRom[256] = "rom.bin";
	if (argc>1)
		strncpy(bootRom, argv[1], strlen(argv[1]));

	success = ectx.emulator->Reset(bootRom, resetvector);

	if (!success)
	{
		fprintf(stderr, "Failed to load ROM\n");
		return -1;
	}

	if (SDL_Init(SDL_INIT_EVERYTHING) != 0)
	{
		fprintf(stderr, "Error initializing SDL2: %s\n", SDL_GetError());
		return -1;
	}
	ectx.window = SDL_CreateWindow("tinysys", SDL_WINDOWPOS_CENTERED, SDL_WINDOWPOS_CENTERED, WIDTH, HEIGHT+8, SDL_WINDOW_SHOWN | SDL_WINDOW_RESIZABLE);

	if (TTF_Init() != 0)
	{
		fprintf(stderr, "Error initializing SDL2_ttf: %s\n", TTF_GetError());
		return -1;
	}
	s_debugfont = TTF_OpenFont("DejaVuSansMono.ttf", 12);
	if (!s_debugfont)
	{
		fprintf(stderr, "Error loading font: %s\n", TTF_GetError());
		return -1;
	}

	if (!SDL_GetWindowSurface(ectx.window))
	{
		fprintf(stderr, "Could not create window surface\n");
		return -1;
	}

	// Compositor surface
	ectx.compositesurface = SDL_CreateRGBSurfaceWithFormat(0, WIDTH, HEIGHT+8, 32, SDL_PIXELFORMAT_ARGB8888);

	SDL_AudioSpec audioSpecDesired, audioSpecObtained;
	SDL_zero(audioSpecDesired);
	SDL_zero(audioSpecObtained);
	audioSpecDesired.freq = 44100;
	audioSpecDesired.format = AUDIO_S16;
	audioSpecDesired.channels = 2;
	audioSpecDesired.samples = AudioQueueCapacity;
	audioSpecDesired.callback = nullptr;
	audioSpecDesired.userdata = &ectx;

	int dev = SDL_OpenAudioDevice(nullptr, 0, &audioSpecDesired, &audioSpecObtained, 0/*SDL_AUDIO_ALLOW_FREQUENCY_CHANGE | SDL_AUDIO_ALLOW_FORMAT_CHANGE*/);
	ectx.emulator->m_audioDevice = dev;
	if (dev)
		AudioQueueCapacity = audioSpecObtained.samples;

	// ONE_MILLISECOND_IN_TICKS to convert from SDL ticks to device units
	const uint64_t ONE_MS_IN_TICKS = 10000;
	uint64_t startTick = SDL_GetTicks64() * ONE_MS_IN_TICKS;
	s_wallclock = SDL_GetTicks64() * ONE_MS_IN_TICKS - startTick;

#if defined(GALLIFREY)
	// Two HARTs
	SDL_Thread* emulatorthreadcpu0ID = SDL_CreateThread(emulatorthreadcpu0, "cpu0", &ectx);
	SDL_Thread* emulatorthreadcpu1ID = SDL_CreateThread(emulatorthreadcpu1, "cpu1", &ectx);
#else
	SDL_Thread* emulatorthreadID = SDL_CreateThread(emulatorthread, "cpu0&1", &ectx);
#endif
	SDL_Thread* audiothreadID = SDL_CreateThread(audiothread, "audio", ectx.emulator);
#if defined(CAT_LINUX)
	SDL_TimerID videoTimer = 0;
#else
	SDL_TimerID videoTimer = SDL_AddTimer(16, videoCallback, &ectx); // 60fps
#endif
#if defined(CPU_STATS)
	SDL_TimerID statsTimer = SDL_AddTimer(1000, statsCallback, &ectx);
#endif
	SDL_Thread* gdbStubThread = SDL_CreateThread(gdbstubthread, "gdbstub", &ectx);

	char bootString[256];
	snprintf(bootString, 255, "%s : %s", emulatorVersionString, bootRom);

	s_textSurface = TTF_RenderText_Blended_Wrapped(s_debugfont, bootString, {255,255,255}, WIDTH);

	fprintf(stderr, "Use the ~ key to reset the emulated CPUs in case of hangs during development\n");

	const uint8_t *keystates = SDL_GetKeyboardState(nullptr);
	uint8_t *old_keystates = new uint8_t[SDL_NUM_SCANCODES];
	memset(old_keystates, 0, SDL_NUM_SCANCODES);

	Axis6 prev_input;
	prev_input.leftx = -11111.f;
	prev_input.lefty = -11111.f;
	prev_input.rightx = -11111.f;
	prev_input.righty = -11111.f;
	prev_input.lefttrigger = -11111.f;
	prev_input.righttrigger = -11111.f;
	uint32_t prev_buttons = 0xFFFFFFFF;

	SDL_Event ev;
	do
	{
		if (SDL_PollEvent(&ev) != 0)
		{
			if (ev.type == SDL_QUIT)
				s_alive = false;
			else if (ev.type == SDL_KEYUP)
			{
				if (ev.key.keysym.scancode == SDL_SCANCODE_GRAVE) // ESP32-C6 does something similar to pass the CPUs a reset signal via CSRs over a dedicated wire
				{
					CCSRMem* csr0 = ectx.emulator->m_bus->GetCSR(0);
					CCSRMem* csr1 = ectx.emulator->m_bus->GetCSR(1);
					csr0->RequestReset();
					csr1->RequestReset();
				}
				else if ((ev.key.keysym.mod & KMOD_CTRL) && ev.key.keysym.sym == 'c')
					ectx.emulator->QueueByte(3);
				/*else if (ev.key.keysym.sym != SDLK_LCTRL && ev.key.keysym.sym != SDLK_LSHIFT && ev.key.keysym.sym != SDLK_RSHIFT)
				{
					if (ev.key.keysym.mod & KMOD_SHIFT)
						ectx.emulator->QueueByte(0x5F & ev.key.keysym.sym);
					else
						ectx.emulator->QueueByte(ev.key.keysym.sym);
				}*/
			}
			else if (ev.type == SDL_CONTROLLERDEVICEADDED)
			{
				ControllerAdd(ectx);
			}
			else if (ev.type == SDL_CONTROLLERDEVICEREMOVED)
			{
				ControllerRemove(ectx);
			}

			// Read joystick events
			if (ectx.gamecontroller)
			{
				// Buttons
				uint32_t buttons = 0x00000000;
				buttons |= SDL_GameControllerGetButton(ectx.gamecontroller, SDL_CONTROLLER_BUTTON_A) ? 0x00000001 : 0;
				buttons |= SDL_GameControllerGetButton(ectx.gamecontroller, SDL_CONTROLLER_BUTTON_B) ? 0x00000002 : 0;
				buttons |= SDL_GameControllerGetButton(ectx.gamecontroller, SDL_CONTROLLER_BUTTON_X) ? 0x00000004 : 0;
				buttons |= SDL_GameControllerGetButton(ectx.gamecontroller, SDL_CONTROLLER_BUTTON_Y) ? 0x00000008 : 0;
				buttons |= SDL_GameControllerGetButton(ectx.gamecontroller, SDL_CONTROLLER_BUTTON_BACK) ? 0x00000010 : 0;
				buttons |= SDL_GameControllerGetButton(ectx.gamecontroller, SDL_CONTROLLER_BUTTON_GUIDE) ? 0x00000020 : 0;
				buttons |= SDL_GameControllerGetButton(ectx.gamecontroller, SDL_CONTROLLER_BUTTON_START) ? 0x00000040 : 0;
				buttons |= SDL_GameControllerGetButton(ectx.gamecontroller, SDL_CONTROLLER_BUTTON_LEFTSTICK) ? 0x00000080 : 0;
				buttons |= SDL_GameControllerGetButton(ectx.gamecontroller, SDL_CONTROLLER_BUTTON_RIGHTSTICK) ? 0x00000100 : 0;
				buttons |= SDL_GameControllerGetButton(ectx.gamecontroller, SDL_CONTROLLER_BUTTON_LEFTSHOULDER) ? 0x00000200 : 0;
				buttons |= SDL_GameControllerGetButton(ectx.gamecontroller, SDL_CONTROLLER_BUTTON_RIGHTSHOULDER) ? 0x00000400 : 0;
				buttons |= SDL_GameControllerGetButton(ectx.gamecontroller, SDL_CONTROLLER_BUTTON_DPAD_UP) ? 0x00000800 : 0;
				buttons |= SDL_GameControllerGetButton(ectx.gamecontroller, SDL_CONTROLLER_BUTTON_DPAD_DOWN) ? 0x00001000 : 0;
				buttons |= SDL_GameControllerGetButton(ectx.gamecontroller, SDL_CONTROLLER_BUTTON_DPAD_LEFT) ? 0x00002000 : 0;
				buttons |= SDL_GameControllerGetButton(ectx.gamecontroller, SDL_CONTROLLER_BUTTON_DPAD_RIGHT) ? 0x00004000 : 0;
				if (buttons != prev_buttons)
				{
					prev_buttons = buttons;

					uint8_t outdata[4];
					outdata[0] = '@';				// joystick button packet marker
					outdata[1] = buttons&0xFF;		// lower byte of modifiers
					outdata[2] = (buttons>>8)&0xFF;	// upper byte of modifiers
					ectx.emulator->QueueByte(outdata[0]);
					ectx.emulator->QueueByte(outdata[1]);
					ectx.emulator->QueueByte(outdata[2]);
				}

				// Axes
				Axis6 input;
				input.leftx = SDL_GameControllerGetAxis(ectx.gamecontroller, SDL_CONTROLLER_AXIS_LEFTX) / 32767.0f;
				input.lefty = SDL_GameControllerGetAxis(ectx.gamecontroller, SDL_CONTROLLER_AXIS_LEFTY) / 32767.0f;
				input.rightx = SDL_GameControllerGetAxis(ectx.gamecontroller, SDL_CONTROLLER_AXIS_RIGHTX) / 32767.0f;
				input.righty = SDL_GameControllerGetAxis(ectx.gamecontroller, SDL_CONTROLLER_AXIS_RIGHTY) / 32767.0f;
				input.lefttrigger = SDL_GameControllerGetAxis(ectx.gamecontroller, SDL_CONTROLLER_AXIS_TRIGGERLEFT) / 32767.0f;
				input.righttrigger = SDL_GameControllerGetAxis(ectx.gamecontroller, SDL_CONTROLLER_AXIS_TRIGGERRIGHT) / 32767.0f;
				ClampAnalogInput(input, 0.1f, 0.9f);
				if (prev_input.leftx != input.leftx || prev_input.lefty != input.lefty || prev_input.rightx != input.rightx || prev_input.righty != input.righty || prev_input.lefttrigger != input.lefttrigger || prev_input.righttrigger != input.righttrigger)
				{
					prev_input = input;

					uint16_t lx = (uint16_t)((input.leftx * 32767.0f) + 32768);
					uint16_t ly = (uint16_t)((input.lefty * 32767.0f) + 32768);
					uint16_t rx = (uint16_t)((input.rightx * 32767.0f) + 32768);
					uint16_t ry = (uint16_t)((input.righty * 32767.0f) + 32768);
					uint8_t lt = (uint8_t)(input.lefttrigger * 255.0f);
					uint8_t rt = (uint8_t)(input.righttrigger * 255.0f);
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

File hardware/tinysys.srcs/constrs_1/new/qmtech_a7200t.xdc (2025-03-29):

## ------------------------------------------------------------------------------------------------------
## Constraints for the QMTECH A7200T board and the custom addon board
## ------------------------------------------------------------------------------------------------------

## (C) 2023 Engin Cilasun
## Applies to expansion board ISSUE-2D/2E/2F
## Please do not change/remove the Clock Groups or False Paths regardless of the warnings during synth
## Also note that changing any of the pin positions will change the timing closure of the device
## due to changes in placing and routing

## ------------------------------------------------------------------------------------------------------
## Clocks
## ------------------------------------------------------------------------------------------------------

set_property -dict {PACKAGE_PIN W19 IOSTANDARD LVCMOS33} [get_ports sys_clk]
create_clock -period 20.000 -name sys_clk_pin -waveform {0.000 10.000} -add [get_ports sys_clk]

## Audio clock @44.100KHz (/512 of clkaudio at 22591KHz)
create_generated_clock -name audiosampleclk -source [get_pins clockandresetinst/peripheralclkinst/clkaudio] -divide_by 512 -add -master_clock clkaudio_peripheralclocks [get_pins socinstance/APU/BUFG_inst/O]

## ------------------------------------------------------------------------------------------------------
## Buttons on the FPGA board - unused
## ------------------------------------------------------------------------------------------------------

## set_property -dict {PACKAGE_PIN Y6 IOSTANDARD LVCMOS33} [get_ports sys_rst_n]

## ------------------------------------------------------------------------------------------------------
## Debug LEDs
## ------------------------------------------------------------------------------------------------------

## 2D
## set_property -dict {PACKAGE_PIN N18 IOSTANDARD LVCMOS33} [get_ports {leds[0]}]
## set_property -dict {PACKAGE_PIN L14 IOSTANDARD LVCMOS33} [get_ports {leds[1]}]
## set_property -dict {PACKAGE_PIN N22 IOSTANDARD LVCMOS33} [get_ports {leds[2]}]
## set_property -dict {PACKAGE_PIN N20 IOSTANDARD LVCMOS33} [get_ports {leds[3]}]

## 2E/2F
set_property -dict {PACKAGE_PIN N17 IOSTANDARD LVCMOS33} [get_ports {leds[5]}]
set_property -dict {PACKAGE_PIN R18 IOSTANDARD LVCMOS33} [get_ports {leds[4]}]
set_property -dict {PACKAGE_PIN Y21 IOSTANDARD LVCMOS33} [get_ports {leds[3]}]
set_property -dict {PACKAGE_PIN T21 IOSTANDARD LVCMOS33} [get_ports {leds[2]}]
set_property -dict {PACKAGE_PIN N18 IOSTANDARD LVCMOS33} [get_ports {leds[1]}]
set_property -dict {PACKAGE_PIN L14 IOSTANDARD LVCMOS33} [get_ports {leds[0]}]

## ------------------------------------------------------------------------------------------------------
## UART Tx/Rx debug port (tie to an external USB-UART cable or other device)
## ------------------------------------------------------------------------------------------------------

## set_property -dict {PACKAGE_PIN T21 IOSTANDARD LVCMOS33} [get_ports debugrx]
## set_property -dict {PACKAGE_PIN Y21 IOSTANDARD LVCMOS33} [get_ports debugtx]

## ------------------------------------------------------------------------------------------------------
## Micro SD card
## ------------------------------------------------------------------------------------------------------

## Sorted by sdcard pin order
## SD     SPI
## DAT[2] -         pin U2:58  [Y18]  sdpin#1
## DAT[3] CSn       pin U2:56  [AA19] sdpin#2
## CMD    MOSI 	    pin U2:54  [AA20] sdpin#3
## VDD    VDD       VCC               sdpin#4
## CLK    SCLK      pin U2:52  [AB21] sdpin#5
## VSS    VSS       GND               sdpin#6
## DAT[0] MISO      pin U2:50  [V18]  sdpin#7
## DAT[1] -         pin U2:48  [U17]  sdpin#8
## SWTCH            pin U2:46  [U20]  sdpin#switch

## 2D/2E/2F
## SPI mode - sorted by sdcard pin order
set_property -dict {PACKAGE_PIN AA19 IOSTANDARD LVCMOS33} [get_ports sdcard_cs_n]
set_property -dict {PACKAGE_PIN AA20 IOSTANDARD LVCMOS33} [get_ports sdcard_mosi]
set_property -dict {PACKAGE_PIN AB21 IOSTANDARD LVCMOS33} [get_ports sdcard_clk]
set_property -dict {PACKAGE_PIN V18 IOSTANDARD LVCMOS33} [get_ports sdcard_miso]
set_property -dict {PACKAGE_PIN U20 IOSTANDARD LVCMOS33} [get_ports sdcard_swtch]
set_property PULLTYPE PULLUP [get_ports sdcard_swtch]

## SD mode - sorted by sdcard pin order
## set_property -dict {PACKAGE_PIN U20 IOSTANDARD LVCMOS33} [get_ports {sd_dat[2]}]
## set_property -dict {PACKAGE_PIN U17 IOSTANDARD LVCMOS33} [get_ports {sd_dat[3]}]
## set_property -dict {PACKAGE_PIN V18 IOSTANDARD LVCMOS33} [get_ports sd_cmd]
## set_property -dict {PACKAGE_PIN AB21 IOSTANDARD LVCMOS33} [get_ports sd_clk]
## set_property -dict {PACKAGE_PIN AA20 IOSTANDARD LVCMOS33} [get_ports {sd_dat[0]}]
## set_property -dict {PACKAGE_PIN AA19 IOSTANDARD LVCMOS33} [get_ports {sd_dat[1]}]
## set_property -dict {PACKAGE_PIN Y18 IOSTANDARD LVCMOS33} [get_ports spi_swtch]
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

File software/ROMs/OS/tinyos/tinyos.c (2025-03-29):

// Boot ROM

#include "rombase.h"
#include "apu.h"
#include "vpu.h"
#include "uart.h"
#include "serialinringbuffer.h"
#include "keyringbuffer.h"
#include "serialinput.h"
#include "commandline.h"
#include "device.h"
#include "gdbstub.h"

#include <string.h>
#include <stdbool.h>
#include <stdio.h>
#include <stdlib.h>

// Names of registers for crash dump
static const char *s_regnames[]={" pc", " ra", " sp", " gp", " tp", " t0", " t1", " t2", " s0", " s1", " a0", " a1", " a2", " a3", " a4", " a5", " a6", " a7", " s2", " s3", " s4", " s5", " s6", " s7", " s8", " s9", "s10", "s11", " t3", " t4", " t5", " t6"};

void ClearStatics()
{
	// Clear device control blocks
	uint32_t *devicecontrol = (uint32_t* )KERNEL_DEVICECONTROL;
	__builtin_memset(devicecontrol, 0, 512); // Clear device control block to zeros, currently there's only UART here

	// Clear keyboard and joystick input buffers
	uint32_t *userinput = (uint32_t* )KERNEL_INPUTBUFFER;
	__builtin_memset(userinput, 0, 1024); // 2x512 bytes for keyboard and joystick input buffers

	// Clear static variables for all systems that use them
	SerialInitStatics();
	CLIClearStatics();
}

void UnrecoverableError()
{
	asm volatile(
		"csrw mie, 0;"			// Disable all interrupt types
		"csrw mstatus, 0;"		// Disable machine interrupts
	);

	// We have experienced a situation which requires a hard-boot
	while (1)
	{
		LEDSetState(0x3F);
		E32Sleep(ONE_SECOND_IN_TICKS);
		LEDSetState(0x02);
		E32Sleep(ONE_SECOND_IN_TICKS);
	}
}

void _stubTask()
{
	// NOTE: This task won't actually run
	// It is a stub routine which will be stomped over by main()
	// on first entry to the timer ISR
	while(1)
	{
		asm volatile("nop;");
	}
}

// Core task for CPU#1 onwards
void __attribute__((aligned(64), noinline)) UserMain()
{
	// Boot sequence for CPU#1
	asm volatile(
		"fence.i;"				// Discard I$
		"csrw 0xFEE, 0;"		// Stop reset
		"csrw mstatus,0;"		// Disable all interrupts (mstatus:mie=0)
		"li sp, 0x0FFDFFF0;"	// Stack base
		"csrr a3, mhartid;"
		"slli a3, a3, 8;"		// hartid*256
		"sub sp, sp, a3;"		// Stack offset for this CPU
		"mv s0, sp;"			// Set frame pointer to current stack pointer
	);

	// Worker cores do not handle hardware interrupts by default,
	// only task switching (timer) and software (illegal instruction)
	uint32_t self = read_csr(mhartid);
	_task_init_context(self);

	struct STaskContext *taskctx = _task_get_context(self);
	_task_add(taskctx, "CPUIdle", _stubTask, TS_RUNNING, HUNDRED_MILLISECONDS_IN_TICKS, self, 0 /*no gp*/, TASK_STACK_POINTER(self, 0, TASK_STACK_SIZE));

	InstallISR(self, false, true);

	while(1)
	{
		asm volatile("wfi;");

		// Yield time back to any tasks running on this core after handling an interrupt
		clear_csr(mie, MIP_MTIP);
		/*uint64_t currentTime =*/ _task_yield();
		set_csr(mie, MIP_MTIP);
	}
}

void HandleCPUError(struct STaskContext *ctx, const uint32_t cpu)
{
	// Handle regular task termination first
	// This is in case we both have a crash and a task termination at the same time
	if (ctx->kernelError & 0x80000000)
	{
		ksetcolor(CONSOLEGREEN, CONSOLEDEFAULTBG);
		DeviceDefaultState(0);
		kdebugprintf("Task %d:%d completed (ret=%d)\n", cpu, ctx->kernelErrorData[0], ctx->kernelErrorData[1]);
	}

	// Strip any termination flag
	ctx->kernelError &= 0x7FFFFFFF;

	// Nothing else to handle
	if (ctx->kernelError == 0)
		return;

	// Now on to actual kernel errors
	ksetcolor(CONSOLERED, CONSOLEDIMGRAY);

	switch (ctx->kernelError)
	{
		case 1: ksetcolor(CONSOLEDEFAULTFG, CONSOLEDEFAULTBG); return; // kdebugprintf("Unknown hardware device"); break;
		case 2: kdebugprintf("Unknown interrupt type"); break;
		case 3: kdebugprintf("Guru meditation"); break;
		case 4: kdebugprintf("Illegal instruction"); break;
		case 5: kdebugprintf("Breakpoint encountered"); break;
		default: kdebugprintf("Unknown kernel error"); break;
	}

	if (ctx->kernelError == 1)
	kdebugprintf(" (0x%08X)", ctx->kernelErrorData[0]);

	kdebugprintf(" on CPU #%d", cpu);
	kfillline(' ');

	// Dump task registers
	if (ctx->kernelError == 4)
	{
		uint32_t taskid = ctx->kernelErrorData[0];
		struct STask *task = &ctx->tasks[taskid];
		kdebugprintf("Task: %d:%d:%d", ctx->hartID, task->HART, taskid);
		kfillline(' ');
		kdebugprintf("IR:%08X", ctx->kernelErrorData[1]);
		kfillline(' ');
		for (uint32_t i=0; i<32; ++i)
		{
			kdebugprintf("%s:%08X ", s_regnames[i], task->regs[i]);
			if ((i+1)%4==0)
				kfillline(' ');
		}
		kdebugprintf("\n");
	}

	ksetcolor(CONSOLEDEFAULTFG, CONSOLEDEFAULTBG);

	// Clear error once handled and reported
	ctx->kernelError = 0;
}
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

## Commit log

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2023-03-24 Comment fixes Moved sie from wire to register Added illegal instruction trap Updated ROM+microcode ROM Added explicit input type enforcement
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2023-04-08 interrupts broken
2023-04-08 No stall, not sure if interrupts work
2023-04-08 Interrupts fixed
2023-04-08 Missing state bit Removed ROM size from DMA unit Updated ROM
2023-04-09 Updated to board ISSUE-1A
    [qmtech_a7200t.xdc]
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2023-04-09 Small logic fixes Updated ROM
    [controlunit.sv]
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2023-04-11 Fixed DMA (without using FIFOs)
2023-04-11 Fixed wrong read offset for DMA
2023-04-11 Fixed misaligned DMA and broken WNS
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2023-04-15 Small fixup for math wait state Updated ROM
    [controlunit.sv]
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2023-04-19 Slightly better timing Fixed wrong FIFO read time
    [controlunit.sv]
2023-04-19 Better volume and timing Fixed a devicerouter typo
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2023-04-29 SD card insertion / removal irq added Updated ROM Fixed some timing related to APU DMA Added support for more than one hw IRQ
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2023-05-03 Added soft reset button Made debouncer a bit less strict Added audio sample buffer reset path Removed reset wires going to clock circuit Updated ROM Added video output disable (black) output Cleaned 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
    [qmtech_a7200t.xdc]
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2023-05-12 Reverted store change due to bad timing Updated ROM
    [controlunit.sv]
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2023-05-14 Some reset and fetch wiring changes
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2023-05-27 Board switched to issue 1E Updated ROM
    [qmtech_a7200t.xdc]
2023-05-30 166MHz core Some linter fixes Added fifo full check to fetch
    [controlunit.sv, qmtech_a7200t.xdc]
2023-05-30 Some reset shuffle for timing
    [controlunit.sv]
2023-05-30 Moved most reset to only affect one register
    [controlunit.sv]
2023-05-30 Fixed a reset issue
    [controlunit.sv]
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2023-07-13 Overall fixes for UART usage
    [rom.c]
2023-07-15 Fixed some minor issues and added some new comments to hardware
    [controlunit.sv, riscvtool.cpp, rom.c]
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2023-07-26 Updated samples and prepped for DMA resolve
2023-07-29 Board changes Rebuilt project Added qspi flash doc
    [expansionboardA.kicad_sch]
2023-07-29 Minor changes ROM won't report terminated for task exit
    [qmtech_a7200t.xdc, rom.c]
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2023-08-01 SDK/sample/board fixes Updated ROM image
    [expansionboardA-B_Cu.gbr, expansionboardA-B_Mask.gbr, expansionboardA-B_Paste.gbr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]
2023-08-05 Final board design for issue 1J Working on USB host - HID support
    [expansionboardA-B_Cu.gbr, expansionboardA-B_Mask.gbr, expansionboardA-B_Paste.gbr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]
2023-08-09 Added missing pullup resistor to reset button to avoid floating Attempting to add device control to turn on keyboard LEDs
    [qmtech_a7200t.xdc]
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2023-08-11 Fixed LED toggles
2023-08-13 minor fixes to usbenum added string usbenum increased poll interval to 20ms
    [expansionboardA.kicad_sch]
2023-08-13 Removed abort on transfer error after device connects
2023-08-13 Fixed pinout to match issue 1J board Added internal pullup to match board changes
    [qmtech_a7200t.xdc]
2023-08-13 Descriptor parser changes Adde missing pullup resistor for sdcard switch
    [qmtech_a7200t.xdc]
2023-08-18 Compacted the PCB design More USB host work
    [expansionboardA-B_Cu.gbr, expansionboardA-B_Mask.gbr, expansionboardA-B_Paste.gbr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]
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2023-08-23 Missing pullup on MAX device reset pins Comment fixes
    [qmtech_a7200t.xdc]
2023-08-24 Added some stall handlers
2023-08-26 SDK cleanup Minor ROM fixes
    [expansionboardA.kicad_sch]
2023-08-26 Added TaskYield() for better timesharing USB Host changes ROM updated Minor linter fixes
    [rom.c]
2023-08-27 Board updates Added fastlz library Added rename() syscall Updated ROM
    [expansionboardA.kicad_sch]
2023-08-27 fastlz compiler error fix HID handler LED usage change Modplayer back to rendering vumeter USB Host work Updated ROM
2023-08-27 fixed usbhost sample to work with ISR
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2023-08-28 Reverted some ROM code that broke
    [rom.c]
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2023-09-03 GPU scanout fixes for repeated scanline vsync position adjusted mouse sample fix
2023-09-05 Rasterizer fixes Sample updates ROM updates
    [rom.c]
2023-09-05 Fixed poll interval issue Fixed GPU scan shift at 640-wide resolution Updated ROM
    [rom.c]
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2023-09-08 Updated pin layout to match board issue 1K
    [expansionboardA.kicad_sch]
2023-09-09 ROM won't process input while another app runs
    [rom.c]
2023-09-10 Removed STM32 from board for now Added debug port back to board Reduced ROM size a bit Added gamepad support (for at least PS4 controller) Wiring for SRAM and UART added
    [expansionboardA-B_Cu.gbr, expansionboardA-B_Mask.gbr, expansionboardA-B_Paste.gbr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]
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2023-09-16 Incremented clock speed to 150MHz Updated constraints for new clock layout Reduced coutners for GPU and APU Replaced registers with BRAM for sample buffer Fixed retired instruction count Minor contro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
    [Assem1.SLDASM, Part1.SLDPRT, Part2.SLDPRT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]
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2023-09-19 Fixes to font output and CLI Updated device ROM
    [rom.c]
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2023-09-19 CLI fixes Updated ROM Updated debug info
    [rom.c]
2023-09-20 Agnes is now C Fixed Doom input Updated ROM
    [rom.c]
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2023-09-23 Fixed overlay ROM support
    [rom.c]
2023-09-23 Added hellorom sample Fixes to ROM overlay
    [rom.c]
2023-09-28 Preparing for HDMI switch Added some detection of USB chip init error Minor fixes to debug stub
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2023-10-10 Revert back rasterizer Switch DVI sync polarity
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2023-10-27 Added first pass of coremark Fixed sim top module Timing tweaks
    [controlunit.sv]
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2023-11-01 Updated board files Make JAL instruction non-stall
    [expansionboardA-B_Cu.gbr, expansionboardA-B_Mask.gbr, expansionboardA-B_Paste.gbr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]
2023-11-10 Fixed ROM overlay/boot path Small debugger related changes
    [rom.c]
2023-11-10 Board issue 2A with HDMI chip
    [expansionboardA-B_Cu.gbr, expansionboardA-B_Mask.gbr, expansionboardA-B_Paste.gbr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]
2023-11-11 Modplayer now directory agnostic Updated ROM with path fixes
    [rom.c]
2023-11-11 Version fixes Behavior fix for getcwd() Absolute path fix for modplayer Keyboard mapping fix
    [rom.c]
2023-11-11 Dev mode color fix
    [rom.c]
2023-11-11 Slightly better debug behavior Board fixes
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2023-11-13 FIx timing for new board layout
2023-11-13 Fix coremark bug for non-threaded application Small change to raster sample
2023-11-13 Much better WNS coremark fix Removed SRAM test (no such device)
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2023-11-28 Raster sample fixes
2023-11-30 Switched to board revision 2B Removed built-in HDMI code, using external Lattice chip
    [expansionboardA.kicad_sch]
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2023-12-10 Switched everything to 12bit RGB mode including the board design
    [expansionboardA.kicad_sch]
2023-12-16 Fixed timing Updated ROM
    [controlunit.sv, rom.c]
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2023-12-23 Small audio sample fix
2023-12-24 More work on agnostic makefiles Some minor bug fixes
    [rom.c]
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2023-12-29 WNS fix Updated ROM Updated board images
    [controlunit.sv]
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2024-01-18 Revert "Removed compressed instruction support"
    This reverts commit b6d25509f7300615f6af926f909f77eb0b875123.
    [controlunit.sv, rom.c]
2024-01-30 Fix builds on MacOS
    [riscvtool.cpp]
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2024-02-17 Data traffic sync fixes
    [riscvtool.cpp]
2024-02-17 Removed debugger code (too much space in ROM) Fixes to serial file transfer
    [riscvtool.cpp, rom.c]
2024-02-18 File transfer work Some memory buffers reordered Graceful termination of file transfer on CRC error
    [riscvtool.cpp, rom.c]
2024-02-18 Fixed sample in README
2024-02-18 Fix function prototype
2024-02-18 Precautin for write error in ring buffer
    [rom.c]
2024-02-20 Reset wiring changes Some rv32 emulator work
2024-02-20 User process start/stop fixed
    [riscvtool.cpp]
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2024-02-27 Fixed output of sat instruction Fixed simulation code and paths
    [controlunit.sv]
2024-02-27 extract reset for unnecessary registers
    [controlunit.sv]
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2024-03-05 Audio fixes as suggested by Ben Stragnell
    [rom.c]
2024-03-06 PBLOCK layout added to avoid overlaps and keep WNS sane
    [qmtech_a7200t.xdc]
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2024-03-11 Stupid antivirus won't let me run a simple SDL2 program
    [tinysys.cpp]
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2024-03-14 Remvoed OPL2 Simplified device router wires Removed placement constraints Updated ROM Updated SDK
    [expansionboardA.kicad_pcb]
2024-03-15 Modified board (added pmod, removed redundant button, rewired power) Updated device to have two CPUs Updated ROM software (Work in progress)
    [expansionboardA.csv, expansionboardA.kicad_pcb, expansionboardA.kicad_sch]
2024-03-15 Revert "Fixorz"
    This reverts commit 4c1b75450612126f650b419f527c1c5cba144750.
    [controlunit.sv, rom.c]
2024-03-15 Revert "Modified board (added pmod, removed redundant button, rewired power)"
    This reverts commit f050528acd5a897698884144464353532d092fb3.
    [expansionboardA.csv, expansionboardA.kicad_pcb, expansionboardA.kicad_sch]
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2024-03-30 Fixed GPIO sample
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2024-03-31 Updated encasing Updated ROM Working on task system
    [1.SLDPRT, 21-0110-C_90-0149-32L_MXM.SLDASM, 403C35D12M00000.SLDASM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]
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2024-03-31 Updated board with 2 more pins between ESP32 and FPGA
    [expansionboardA-B_Cu.gbr, expansionboardA-B_Mask.gbr, expansionboardA-B_Paste.gbr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]
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2024-04-06 Added UART listener to ESP32 (on serial 1) Updated ROM to listen to ESP32 serial pins Added UART sample to send data to ESP32 SDK and hardware still a bit WiP but works
    [expansionboardA.kicad_sch]
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2024-04-07 Some OS changes to report kernel errors Updated raster code and sample Some IRQ changes to reduce clock mismatch Reordered IRQ bits
    [casebottom.SLDPRT, casetop.SLDPRT]
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2024-04-08 Removed inf loop chance by echoing UART input Added LED blink on incoming UART data Updated ROM
    [expansionboardA.kicad_sch]
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2024-04-08 Removed usb sdrial (MAX3420) support and migrated to UART over ESP32 Shifted device address map to match hardware Updated ROM Updated samples
    [casebottom.SLDPRT]
2024-04-08 Fixed watchdog timer issue in uart bridge
    [uart_async_rxtxtasks_main.c]
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2024-04-08 Updated gateware, ROM version, and board schematic to remove MAX3420 support
    [expansionboardA.kicad_pcb, expansionboardA.kicad_sch]
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2024-04-13 Dual core, but timing won't close yet
    [controlunit.sv]
2024-04-13 Timing fixes Board updates
    [expansionboardA.kicad_pcb]
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2024-04-15 Changes/notes for multiheart Reset changes for timing
    [rom.c]
2024-04-15 CPU#0 can now reset CPU#1
    [rom.c]
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2024-04-19 Missing coherency flag on ROM
    [rom.c]
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2024-04-21 OS path processing fixes Removed file transfer code
    [rom.c]
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2024-04-21 Prevent running multiple ELF per code without MMU
    [rom.c]
2024-04-22 Added task halt on error to CPU1
    [rom.c]
2024-04-22 Fix stack accidental overlap between cores Some VPU code cleanup
    [rom.c]
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2024-04-26 A bit better reset and WFI handling
    [rom.c]
2024-05-04 Working on core reset
    [controlunit.sv]
2024-05-04 Removed most of dedicated reset logic
    [rom.c]
2024-05-05 Timing and boot corrections
    [rom.c]
2024-05-06 Updated enclosure to make sure SDCard doesn't fall into the case
    [casebottom.SLDPRT, casetop.SLDPRT]
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2024-05-07 CPU zero handles crash dump of all CPUs
    [rom.c]
2024-05-07 Fixed stack error causing CPU#1 to halt Updated ROM Added shadow CSR (read-only) for PC
    [controlunit.sv]
2024-05-09 Floor planning and reset pass
    [qmtech_a7200t.xdc]
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2024-05-11 Added missing reset line for UART
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2024-05-15 Fixed code sample makefiles Added experimental XM playback support to modplayer sample, renamed it to 'play' Added prebuild sdcard folder and some data files
2024-05-16 Switched form separate libs to a more capable mod player lib (tons of supported formats!), player is also much simpler! Added some missing ROM functions (gettimeofday and _stat) Updated hardware timi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
2024-05-18 Fixed wrong sound sample count and glitches in Doom's sound code
2024-05-18 Updated wrong clock (was 170MHz, should be 150MHz) in one IP Added cascaded reset for better timing Fixed some reset logic in ALU and BLU
    [controlunit.sv]
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2024-06-11 CSR reset mechanism added
    [bus.cpp, csrmem.cpp]
2024-06-11 Updated to latest ROM, fixed some errors in reset
    [bus.cpp, csrmem.cpp]
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2024-06-11 release build and video fixes
    [bus.cpp, csrmem.cpp, tinysys.cpp]
2024-06-11 Fix memory read case error (missing break) Video changes
    [bus.cpp, tinysys.cpp]
2024-06-11 Add missing mul and div
    [bus.cpp, tinysys.cpp]
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2024-06-11 Some threading fixes
2024-06-11 Fix hang on boot with the real ROM Switch to using real ROM from hardware
    [bus.cpp, sdcard.cpp]
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2024-06-13 More fixes, ISR doesn't function properly yet
    [csrmem.cpp]
2024-06-13 fixed emulator on macos
    [csrmem.cpp, tinysys.cpp]
2024-06-17 UART and ISR fixes Bumped ROM version Minor fix to task yield (only disables timer interrupt now)
    [bus.cpp, csrmem.cpp, rom.c]
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2024-06-17 Second core ready with a minor glitch
    [bus.cpp, csrmem.cpp]
2024-06-17 Reboot issues on hart#1
    [bus.cpp, csrmem.cpp]
2024-06-17 Updated ROM Memory debug view added Still problematic reboot for hart#1
    [bus.cpp, csrmem.cpp]
2024-06-17 Fixed dual CPU boot
    [bus.cpp, rom.c]
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2024-06-22 Audio will fake buffer swap until it's implemented
    [bus.cpp]
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2024-06-22 Fixed 12bpp color upscale bug
    [tinysys.cpp]
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2024-06-23 memory barrier changes ROM inner loop shortened
    [rom.c]
2024-06-23 Fix 60Hz timer for emulator ROM main task changes UART routine changes
    [rom.c, tinysys.cpp]
2024-06-24 Updated paths and added missing files
    [sdcard.cpp]
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2024-06-28 audio rate and audio start/stop fixes
    [tinysys.cpp]
2024-06-28 Fix sample count in pseudo audio device
    [tinysys.cpp]
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2024-07-07 Hardware and SDK changes in preparation for misaligned DMA support Minor ROM tweaks
    [rom.c]
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2024-07-12 Some optimizations to short-cut to sysmem DMA can't access other devices as with real hardware now
    [bus.cpp, csrmem.cpp]
2024-07-12 Added msvc project to emulator Some minor compile warning fixes
    [sdcard.cpp, tinysys.cpp]
2024-07-13 Sample rate support for audio output Minor fixes and changes to code and comments
    [csrmem.cpp, tinysys.cpp]
2024-07-17 DMA fix
2024-07-17 Some more DMA and mem fixes
2024-07-17 One last DMA and mem fix
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2024-07-18 LED color fix
2024-07-19 fix error in audio rate selection
    [tinysys.cpp]
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2024-07-26 build fix for macos
    [tinysys.cpp]
2024-08-03 Minor ROM cleanup Updated emulator binaries Fixed an issue with build command line causing bad paths
    [rom.c]
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2024-08-31 Moved core#1 one tile lower Added more reset delay lines Fixed the odd sdcard reset logic Got rid of initial values for some registers
    [qmtech_a7200t.xdc]
2024-09-01 Fixed pblock typo Reset fix for icache
    [qmtech_a7200t.xdc]
2024-10-23 Fix VC project files
    [tinysys.cpp]
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2024-10-28 Fixed timer behavior
2024-10-28 More fixes to wall clock
    [csrmem.cpp, tinysys.cpp]
2024-11-02 First pass of misaligned target support for DMA Reduced GPIO pins connected to the CPUs to free up a reset line from ESP32 Updated DMA sample
    [qmtech_a7200t.xdc]
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2024-11-03 Fixed DMA copy error on first byte for aligned masked data Updated ROM Updated dmatest sample Updated gateware Fixed DMA automask error
    [qmtech_a7200t.xdc, rom.c]
2024-11-03 Fixed reboot missing cursor bug Updated ROM Updated pblocks to move FPUs away
    [qmtech_a7200t.xdc, rom.c]
2024-11-04 Some hardware reset changes ESP32-C6 firmware update
    [uart_async_rxtxtasks_main.c]
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2024-11-14 Fixed hblank circuit to keep triggering anywhere below hblank line Added 10 bit scanline count to VPU code Updated samples and fixed a few issues Updated ROM DMA and hblank need work on emulator side
    [tinysys.cpp]
2024-11-14 minor updates to hblank sample to work on stability
2024-11-14 minor dma fixes
2024-11-14 Proper misaligned DMA
2024-11-15 Serial port output fix Removed ring buffer Added some SDK functions Fixed a minor hardware inefficiency Updated ROM
    [expansionboardA.kicad_sch]
2024-11-16 Added remote CPU reset ability via tilda character over UART
    [qmtech_a7200t.xdc, uart_async_rxtxtasks_main.c]
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2024-11-16 Fixed some enclosure issues
    [casebottom.SLDPRT, casetop.SLDPRT]
2024-11-16 Added scratchpad memory (64K) Updated ROM Updated documentation Updated emulator with the CPU reset logic
    [qmtech_a7200t.xdc, rom.c, tinysys.cpp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]
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2024-11-17 Fix to maintain reset control pin state on usb serial disconnect
    [qmtech_a7200t.xdc, uart_async_rxtxtasks_main.c]
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2024-11-18 moved uart intercept setting to app side (for OS apps)
    [expansionboardA.kicad_sch]
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2024-11-20 Fixed some file transfer issues
    [recv.cpp, riscvtool.cpp, uart_async_rxtxtasks_main.c]
2024-11-22 Updated recv command Added command push to riscvtool Updated ROM Updated device layout Removed stale files CPU#0/#1 faults now reset CPU#1 Updated gateware
    [qmtech_a7200t.xdc, recv.cpp, riscvtool.cpp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]
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2024-11-25 Stack overlap and task fixes
    [rom.c]
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2024-11-30 Some reboot/reset work Moved ADC to MIG as internal component Updated ROM startup sequence
    [expansionboardA.kicad_pcb]
2024-12-01 Board updates for version 2G Factory test ROM update
    [expansionboardA.kicad_pcb, expansionboardA.kicad_sch]
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2024-12-09 Safer reboot with both fetch and control tied to cpuresetreq
    [controlunit.sv]
2024-12-09 WNS fix ESP32 ROM image fix
    [uart_async_rxtxtasks_main.c]
2024-12-09 Added one second timer for aborting the reboot request Fixed dump code
    [dump.cpp, uart_async_rxtxtasks_main.c]
2024-12-09 File upload code reworked Added LZ4 compression
    [recv.cpp, riscvtool.cpp, uart_async_rxtxtasks_main.c]
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2024-12-11 Removing USB Host, eventually to be replaced by bluetooth Board revision 2G in the works
    [qmtech_a7200t.xdc, rom.c]
2024-12-13 minor code updates and comments removed async resets cpuresetreq is an actual hardware reset now placed missing IR reset updated ROM updated Vivado project
    [controlunit.sv, uart_async_rxtxtasks_main.c]
2024-12-14 Added missing reset lines Some syntax and typo fixes in OS code Updated ROM
    [rom.c]
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2024-12-17 Starting to switch to S3 and new board
    [expansionboardA.kicad_sch]
2024-12-18 missing UART reset lines added minor ESP32 code changes
2024-12-18 updated riscvtool added terminal mode to riscvtool added missing rx/tx resetn signal
    [riscvtool.cpp]
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2024-12-24 Started work on new board Added some new device documents Disabled in-ROM GDB to do the initial pass on emulator GDB-stub Updated ROM
    [1-1825027-1.step, 403C35D12M00000.step, 676430910.stp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]
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2024-12-25 Fix to stub binary decoder
    [tinysys.cpp]
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2024-12-28 Updated board and hardware to reset ESP32 from the FPGA
    [expansionboardA.kicad_pcb, expansionboardA.kicad_sch, expansionboardB.kicad_pcb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]
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2025-01-01 Resistor mistake
    [expansionboardB.kicad_sch]
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2025-01-05 fix for riscvtool file path compilcation
    [riscvtool.cpp]
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2025-01-08 Minor fix to keys sample
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2025-01-10 Crash fix for audio device detection path
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2025-01-16 Started to get rid of the video and audio chips and circuitry
    [2086581051.step, LTST-C195KGJRKT.step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]
2025-01-18 Board updates HDMI unit updates Removed redundant files Removed redundant constraints
    [expansionboardA-B_Cu.gbr, expansionboardA-B_Mask.gbr, expansionboardA-B_Paste.gbr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]
2025-01-18 Auto-connect on UART loss Audio capture lag fix attempts
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2025-01-19 More updates towards DMA fix
    [qmtech_a7200t.xdc]
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2025-01-21 Updates to board and mechanical files Rebuilt tinyremote exe Updated device with WNS fixes
    [casebottom.SLDPRT, casetop.SLDPRT, encbottom.SLDPRT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]
2025-01-25 Updated ROM to handle key input better Matched emulator to hardware LED states Added 2 more LEDs (diagnosis, red+green) Updated ROM to work with diagnosis LEDs Placement and timing fixes
    [qmtech_a7200t.xdc, rom.c, tinysys.cpp]
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2025-02-02 Corrections to uploader, tinyremote, hardware and device
    [recv.cpp]
2025-02-02 device report minor fix
2025-02-03 Fixed file upload progress bar Rebuilt ROM Broke timing but fixed second core
    [qmtech_a7200t.xdc]
2025-02-04 Timing closure fixed properly this time Updated ROM Updated SDK Updated hblank sample Updated hblank interrupt hardware Removed redundant resets
    [controlunit.sv, rom.c]
2025-02-05 Updated tinyremote to work with more capture devices (resolution fix)
2025-02-08 Bugfix for audio playback device enumeration
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2025-02-11 Revert "Updated emulator samples"
    This reverts commit b5f57141ca1635c609f5a752fa754637d936ceb6.
    [expansionboardA.kicad_pcb, expansionboardA.kicad_sch]
2025-02-13 Make sure gerber files are same as those manufactured
    [expansionboardA-B_Cu.gbr, expansionboardA-B_Mask.gbr, expansionboardA-B_Paste.gbr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]
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2025-02-25 Software can't cope with out-of-range devices, simply return 0
    [expansionboardB.kicad_sch]
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2025-03-01 Fixed scancode key entry
    [tinysys.cpp]
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2025-03-03 Fix hang on exit if debugger was never attached
    [tinysys.cpp]
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2025-03-05 Some task related fixes Updated ROM for emulator Rebuilt emulator Rebuilt riscvtool
    [rom.c]
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2025-03-10 Updates to task code Updates to mod player sample ROM updated Device rebuilt with new ROM CPU reset further delayed CPU reset also resets instruction FIFO CLI does not handle task exit state (deferre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
    [rom.c]
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2025-03-15 Critical file upload fix
    [riscvtool.cpp]
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2025-03-21 small fixes for unused code paths
    [sdcard.cpp]
2025-03-21 fixed mac builds updated macos emulator binary
    [sdcard.cpp]
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2025-03-23 Added missing vectored interrupt support to emulator (unused)
2025-03-25 Reset logic changed to reboot entire FPGA ROM updates
    [qmtech_a7200t.xdc, rom.c]
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2025-03-28 fix macos/linux build of riscvtool rebuilt ROM slightly smaller
    [riscvtool.cpp]
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2025-03-29 Scratchpad memory is now 64K Reset is now more robust ROM updated
    [qmtech_a7200t.xdc, tinysys.cpp]
2025-03-29 Fix for linux access issues to GL context on a timer callback
    [tinysys.cpp]
2025-03-30 Support Resizing Emulator (#15)
    With this change, you can resize the emulator window and the image stretches. It's not always pretty, but it does always work.
    To handle resizing, we don't even need to respond to the window resize events. We only need to:
    1. Tell SDL to make the window resizable
    2. Use the correct Surface once it's been resized.
    3. When copying from the composite surface to the window surface, we need to use `SDL_BlitScaled` over `SDL_BlitSurface`, which handles resizing.
    While debugging it, I realized the `SDL_Surface` is being held onto too long, _and_ the SDL docs explicitly call it out as "do not free" [here](https://wiki.libsdl.org/SDL2/SDL_GetWindowSurface):
    > A new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
    [tinysys.cpp]
2025-03-30 Fixed leaking SDL surface. FIxed leaking decoded blocks due to looking up map with wrong key. (#16)
    [tinysys.cpp]
2025-03-31 Frame pacing fix for linux
    [tinysys.cpp]
2025-03-31 Fix sdcard memleaks (#17)
    * Fixed leaking SDL surface. FIxed leaking decoded blocks due to looking up map with wrong key.
    * Fixed memory leaks when refreshing emulator sdcard filesystem.
    * Fixed memory leaks when refreshing emulator sdcard filesystem.
    ---------
    [sdcard.cpp]
2025-03-31 Small Memory Leak Fixes & Fix VS Project Paths (#18)
    * Fix Emulator VS Project Include Paths
    The previous paths were hardcoded to local directories which prevented
    the solution from compiling properly on other machines.
    This change updates the paths to use VS path macros instead which makes
    the include paths relative to the project directory.
    * Fix Small Memory Leak in RV32 Emulator
    The SDecodedBlock structures allocated as part of m_decodedBlocks were
    never being deleted when the map was cleared (during reset and fence
    instructions).
    This change adds logic to delete the structures whenever the map is
    cleared which resolves the leak.
    * Add Various Missing Deletes
    Several places in the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
    [bus.cpp, tinysys.cpp]
2025-04-05 Updated missing bus acquire and updated binary
    [bus.cpp, tinysys.cpp]
2025-04-05 Fix a fatal error
    [bus.cpp, tinysys.cpp]
2025-04-07 fixed some stats display
    [tinysys.cpp]
2025-04-08 Fixed hardware bug (f2ui)
    [controlunit.sv]
